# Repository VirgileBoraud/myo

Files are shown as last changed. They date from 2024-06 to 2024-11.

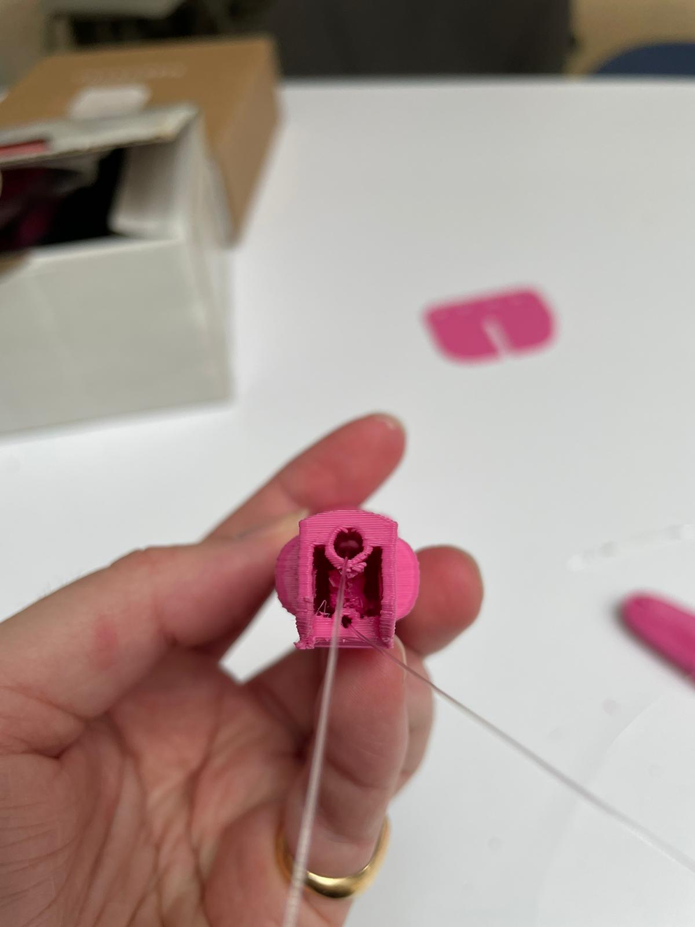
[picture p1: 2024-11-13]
Photos&Vidéos/montage5.jpg

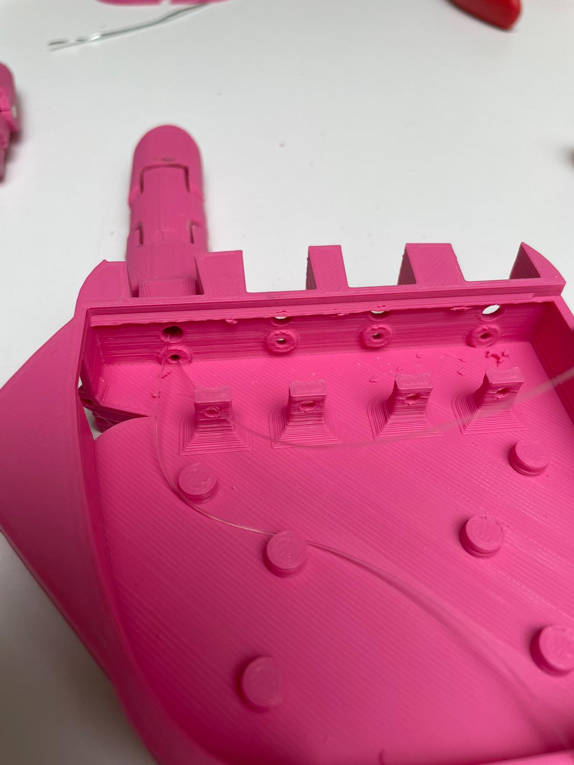
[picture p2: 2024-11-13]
Photos&Vidéos/montage6.jpg

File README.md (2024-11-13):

# Projet_2B09

Vous trouverez tout les programmes dans le dossier correspondant, de même pour les fichiers de modélisation dans le dossier CAO.

Le fichier Projet2B09 est le rapport du projet. 

Lien du projet dont nous nous sommes inspiré:
https://github.com/ashpande/ProstheticHand

Lien présentation canva:
https://www.canva.com/design/DAGHKcEUw74/4D-0PP82Fv-sbKtp_eXOTw/edit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

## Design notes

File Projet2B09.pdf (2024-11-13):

### Page 1 sur 45

# Projet d’avant-bras Myoélectrique

Par Virgile Boraud, Léa Forêt et Rayan Bacha

### Page 2 sur 45

# SOMMAIRE

### Page 3 sur 45

# Remerciements

Nous tenons à remercier toutes les personnes qui ont contribué à la réalisation de ce projet.

Tout d’abord nous remercions chaleureusement et exprimons notre gratitude envers H. Guan, notre référent ainsi que A. Caldas pour leurs conseils et leur encadrement.

Un merci spécial aux membres de l’atelier et du fablab, N. Guillet-Lhermite et C. Thery pour leur assistance technique et leur expertise dans la création de notre prototype.

Merci également à l’ESME ainsi que SupBiotech pour nous avoir offert les ressources nécessaires lors de notre parcours pédagogique.

Enfin, nous remercions nos proches pour leur soutien tout au long du projet.

### Page 4 sur 45

# Présentation

## Qui sommes-nous ?

Nous sommes un groupe de trois étudiants de 4ème année d’école d’ingénieurs composé d’un élève de SupBiotech et deux élèves de l’ESME de la majeure Biomécanique et Robotique médicale. Ce projet s’inscrit dans le cadre de notre formation sous la supervision de Henry Guan, notre référent.

## Quel est notre projet ?

Etant tous trois intéressés par le fonctionnement des prothèses des membres, nous avons décidé de nous orienter vers un projet de ce type. Notre choix s’est porté vers une prothèse de bras, la prothèse de jambe étant soumise à des pressions mécaniques trop difficile à reproduire dans le cadre de ce projet. Nous avons finalement décidé de nous focaliser sur la main et l’avant-bras car les biomécanismes sous-jacents etleurs fonctions ont particulièrement attiré notre attention.

Nous avons décidé d’utiliser un biosignal afin d’actionner l’ouverture et la fermeture de la main. Trois biosignaux s’offrent ainsi à nous : nerveux, cérébraux (encéphalogramme) et myoélectriques. Nous avons déterminé que les signaux myoélectriques conviennent le mieux pour notre projet, ces derniers étant aisément traitables pour capter un seul seuil afin d’activer le moteur responsable de la fermeture/ouverture de la main.

Notre objectif est ainsi d’assembler une prothèse de main myoélectrique et de s’assurer de sa fonctionnalité.

## Organisation de l’équipe

Chacun des membres de l’équipe a été impliqué équitablement dans le projet. Des réunions hebdomadaires avec notre référent ont étaient organisées et plus régulièrement des discussions entre membres de l’équipe. Ces réunions permettant de faire le point sur les avancements de chacune des parties du projet.

Nous avions au début du projet défini quatre grandes parties pour ce projet :

- Recherches préparatoires
- Conception et impressions 3D
- Electronique
- Programmation

### Page 5 sur 45

Nous n’avions pas pris en compte que le montage même de la main avec le besoin de réimprimer et modifier les fichiers SolidWorks nous rajouterai beaucoup de travail et aurait pu être considéré comme une grande partie à part entière.

Figure 1 : Planning initial du projet

En effet, ce planning initial (Figure 1) créé début mars a dû être adapté à de nombreuses reprises. La phase de conception a en effet eu lieu tout au long du projet, suite aux différents problèmes rencontrés lors du montage et des tests, de multiples pièces ayant dû être modifiées.

Concernant la répartition des tâches, nous avons tous participé à la recherche préparatoire pour pouvoir ensuite construire notre projet. Les autres parties ont aussi été traitées de manière globale par l’ensemble de l’équipe avec plus ou moins une spécialisation dans l’un ou l’autre des domaines.

## Contexte médical et problématique

L’amputation de la main et/ou d’une partie de l’avant-bras estsouvent due à des accidents, des blessures ou des maladies (ex : complication du diabète). Cette amputation peut entraîner une perte de mobilité et de fonctionnalité des patients concernés. En effet, la perte de l’articulation du poignet et de la main limite et peut rendre impossible d’accomplir certaines tâches du quotidien essentielles (ex : se nourrir, se déplacer, travailler, …).

C’est pour répondre à cette problématique que nous réalisons ce projet. Notre prothèse a pour but de redonner au patient la possibilité d’attraper des objets permettant ainsi de recouvrer une partie de sa mobilité et de son indépendance.

### Page 6 sur 45

# Anatomie et biomécanique de la main

A] Fonctions de la main

La main opère 2 fonctions principales :

- le tact, permettant la sensibilité tactile, avec reconnaissance du relief, taille et distance de 2 reliefs, consistance et température ainsi que le rétro-contrôle cérébral des gestes fins ou des gestes en force
- la préhension, avec possibilité d’opposition du pouce

Cette action de préhension permet de réaliser diverses fonctions comme illustrées ci-dessous :

Figure 2 : Différentes actions possible par la fonction de préhension de la main

Dans le cadre de notre projet, nous avons donc décidé de fabriquer une prothèse pouvant reproduire cette fonction de préhension.

B] Structure des articulations du doigt

L’articulation métacarpo-phalangienne permet le mouvement des phalanges sur un angle de 120° relatif à l’axe des métacarpes. L’articulation de la première et la seconde phalange permet un mouvement sur un angle de 120° relatif à l’axe de la première phalange. L’articulation de la seconde et troisième phalange permet un mouvement de 80° relatif à l’axe de la seconde phalange.

Figure 3 : Schéma des angles des mouvements des articulations du doigt

Ces mouvements cumulés permettent la flexion du doigt pour la fonction préhensile.

### Page 7 sur 45

Dans le cadre de notre projet, il nous faut donc nous assurer que notre prothèse puisse reproduire ces mouvements de flexion.

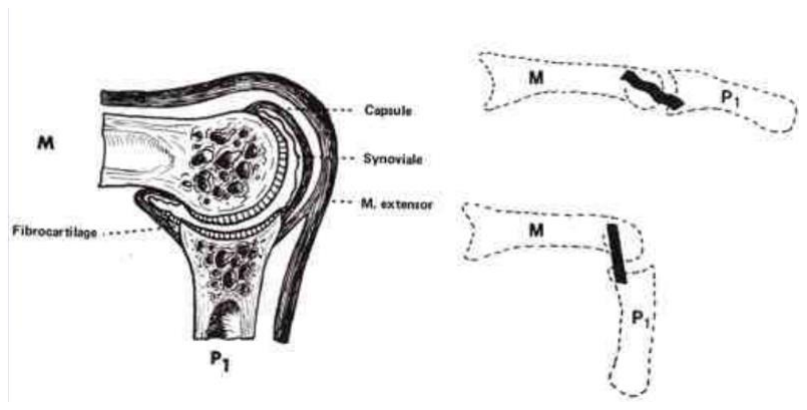
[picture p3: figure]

Figure 4 : Schéma de l’articulation métacarpo-phalangienne

Schéma de l’articulation métacarpo-phalangienne

L’articulation métacarpo-phalangienne permet le mouvement vu précédemment grâce à :

- la forme concave du métacarpe et de la phalange
- la capsule et le liquide synoviale permettant de réduire les frictions du mouvement
- le muscle extenseur de la main, permettant de réaliser le mouvement d’extension du doigt

C] Muscles extenseurs des doigts

### Le muscle extenseur des doigts de la main (en rouge vif sur la figure 5) est positionné sur l’humérus et l’ulna et permet par sa contraction de

déclencher l’extension des doigts.

Figure 5 : Muscle
extenseur des
doigts de la main

### Page 8 sur 45

### Son action est toutefois complémentaire de l’action des muscles extenseurs individuels à chaque doigt (en rouge sur le schéma ci-contre), dont la contraction combinée à celle du muscle précédent

permet l’extension du doigt. Ainsi, pour étendre l’index,

### il faut la contraction du muscle extenseur des doigts de la main et du muscle extenseur de l’index. Pour étendre tous les doigts, il faut la contraction du muscle extenseur des doigts de la main ainsi que de chaque

muscle extenseur du doigt individuel.

D] Flexion des doigts de la main

La flexion des doigts de la main commence par la contraction de deux muscles de l’avant-bras (schéma ci-dessous), le muscle fléchisseur profond des doigts et le muscle fléchisseur superficiel des doigts. Le muscle fléchisseur profond des doigts de la main permet la flexion des articulations interphalangiennes distales des 4 doigts longs, alors que le muscle fléchisseur superficiel des doigts est fléchisseur des phalanges moyennes sur les phalanges proximales et des phalanges proximales sur les métacarpiens.

Figure 7 : Muscles fléchisseur superficiel (gauche) et profond (droite)

Les tendons du muscle fléchisseur profond des doigts courent le long des doigts sur leur face inférieure et la contraction du muscle entraîne ainsi la flexion des doigts.

Figure 6 : Muscle extenseur d’un doigt

### Page 9 sur 45

# Histoire et état de l’art des prothèses

Les prothèses servent à remplacer des organes, des membres ou une articulation par des appareils artificiels permettant de restaurer la fonction compromise. Elle permet non seulement d’essayer de rétablir la fonctionnalité de la partie du corps concernée, mais aussi à améliorer la capacité de mouvement perdu, soutenir des structures corporelles affaiblies ou déformées ou à améliorer l’aspect esthétique (voir les gueules cassées de la
Première Guerre mondiale). Il en existe 2 types, les
externes, comme les membres artificiels, et les internes
comme les valves cardiaques et les implants dentaires. Nous ne parlerons ici que de ceux qui nous intéressent, c’est-à-dire les externes.

Les premières traces de prothèse datent de l’Egypte Antique, des archéologues ont trouvé sur la momie d’une femme une prothèse de doigt de pied faite en bois et en cuir datant de 600 avant JC. Il y serait également fait mention dans les récits de Hérodote en 484-425 av. J.-C. décrivant un substitut en bois d’un pied préalablement, histoire reprise par Plutarque par la suite (voir jambe de Capoue).

Les prothèses ont ensuite été utilisées tout du long du moyen-âge et de la renaissance, généralement en fer ou en métal, certaines pouvaientservir dans des cas pratiques, comme le crochet ou la célèbre jambe de bois des pirates, dont le plus connu utilisateur serait un certain François Le Clerc, surnommé à juste titre “Jambe-de-bois" (voir figure 2). D’autres n’étaient qu’à des fins cosmétiques comme nous pouvons le voir sur la figure 3.

Figure 8 : Plus ancienne prothèse datant de l’Egypte Antique

Figure 9 : Prothèse
en bronze

Figure 10 : Représentation de François Le Clerc

### Page 10 sur 45

C’est au XVIème siècle que les prothèses reçoivent de nouvelles avancées. Un chirurgien français, Ambroise Paré, à créer de nouvelles façons d’amputer ce qui a permis d’avoir de plus grandes chances de guérison et permet l’installation d’appareils de remplacement (voir figure 11) qui permettaient un fonctionnement très basique de la main en métal pour les soldats amputés. Le chirurgien cherchait à reproduire le mouvement naturel grâce à la mécanique.

Différentes avancées durant le 1er et 2ème révolution industrielle permettent certaines avancées dans la fabrication des matériaux composant les prothèses. Celles-ci sont alors plus légères, plus souples, plus robustes et plus fonctionnelles.

Figure 11 : Prothèse médiévale

Figure 12 : Illustration
d’Ambroise Paré

Figure 13 : Prothèse possédant des articulations

Figure 14 : Homme portant des prothèses au début du XIXème siècle

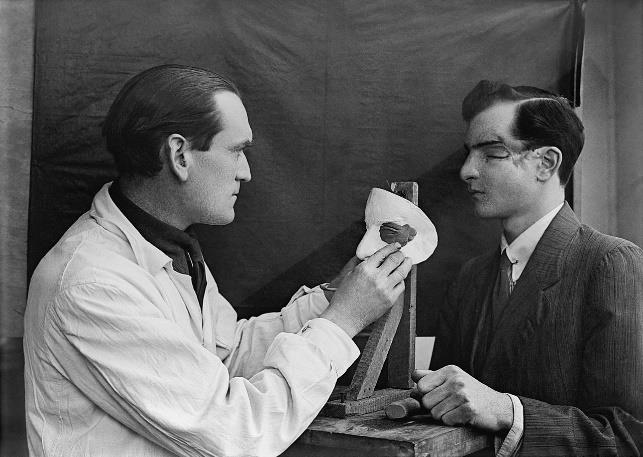
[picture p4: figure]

### Page 11 sur 45

C’est lors de la Première Guerre Mondiale que la demande de prothèsesliées aux blessures de guerre explose. De grandes avancées en chirurgie et prothèse voient le jour. L’un des exemples les plus connus est « les gueules cassées ». Certaines images que nous ne montrerons pas ici montrent des personnes totalement déformées par leurs blessures de guerre se métamorphoser après une chirurgie maxillo-faciale et des prothèses esthétiques ou/et des masques.

C’est après la Seconde Guerre mondiale que l’on voit apparaître une réelle envie par les Etats de financer le développement de prothèses comme les USA en 1948 après diverses controverses sur le manque de considération des soldats amputés. De nombreuses prothèses voient alors le jour. Nous pouvons citer par exemple les prothèses Jaccard (voir figure 16). Faites à partir de matériaux locaux, purement fonctionnels et dépourvus d’artifices esthétiques, elles permettent aux plus démunis de se procurer des prothèses jusqu’alors inaccessibles. Révolutionnant le soin des amputés, ses concepteurs, les frères Jaccard, viendront en aide aux plus démunis à travers le monde.

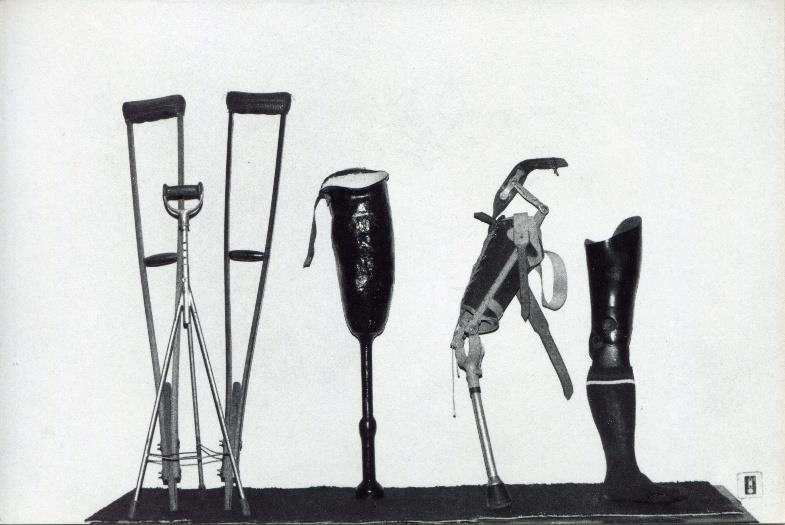
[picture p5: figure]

Finalement, c’est de la fin du XXème siècle à aujourd’hui que les prothèses n’ont cessé de se diversifier. De la simple jambe de bois, aux prothèses bioniques utilisant plusieurs capteurs et des algorithmes complexes, en passant par les prothèses imprimables possibles grâce aux imprimantes 3D. Nul doute que les prochaines décennies verront de nouvelles innovations dans le domaine.

Figure 15 : Confection d’un masque pour un soldat britannique

Figure 16 : Différentes prothèses « Jaccard »

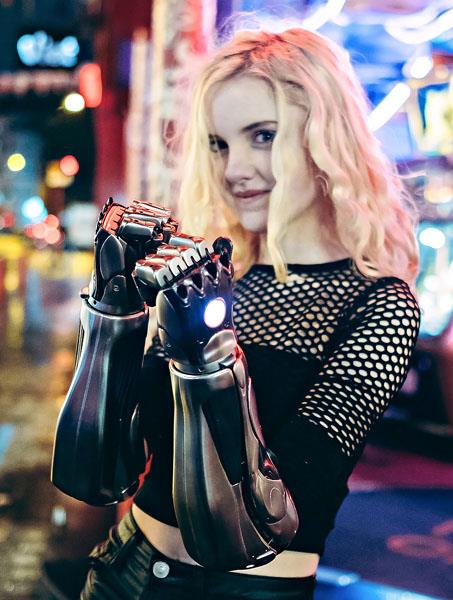
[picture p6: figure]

### Page 12 sur 45

Figure 17 : Prothèse e-NABLE

Figure 18 : Prothèse de bras « Hero-Arm »

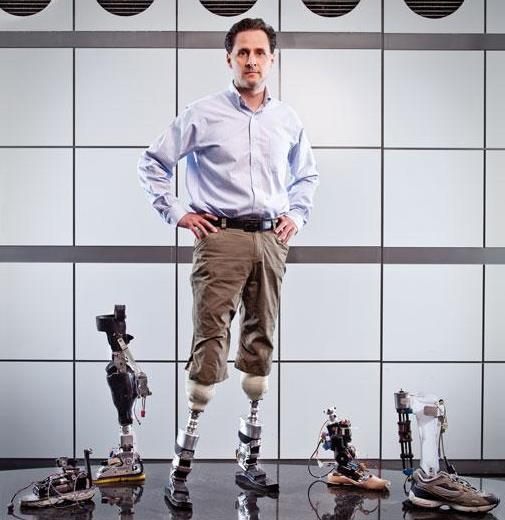
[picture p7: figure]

Figure 19 : Prothèse de jambe HI-tech

### Page 13 sur 45

# Cahier des charges

Nous avons établi un cahier des charges initial pour notre prothèse myoélectrique. Nous nous sommes basés sur notre propre appréciation de ce projet ainsi que différents cahiers des charges proposés dans le cadre de concours de modélisation/innovation disponibles en ligne.

Concernant la structure :

- Imperméable
- Inoxydable
- Aisément nettoyable
- Températures de -10°C à +50°C
- Poids entre 0,5 et 1% du poids de corps total de l’individu à on part sur un homme de 80 kilos à poids entre 400-800g
- Longueur bras (environ 28cm)
- Longueur main (environ 20cm)

Analyse post-projet :

Les critères d’imperméabilité et d’inoxydabilité n’ont pas pu être intégrés au projet final. En effet, le moteur que nous utilisons s’est trouvé trop grand pour être intégré à la prothèse d’une manière permettant le bon déroulement/enroulement du fil. Un axe moteur différent ou de taille réduite aurait permis son intégration dans l’avant-bras sans élément extérieur. Cette partie extérieure du moteur vient aussi mettre à mal ce critère d’imperméabilité. Enfin, les autres éléments (carte Arduino, batterie, ...) sont aussi de taille trop importante pour être intégrés dans la prothèse directement.

Concernant l’alimentation :

- Possibilité de rechargement USB ou batterie interchangeable facilement
- Interrupteur pour allumer et éteindre la prothèse
- Indicateur visuel du niveau de la batterie
- Capable d’alimenter 1 moteur

### Page 14 sur 45

Analyse post-projet :

Nous avons bien une batterie rechargeable qui alimente l’entièreté de notre système, notre batterie comprend un indicateur visuel de son état de recharge et un bouton on/off. Nous avons gardé l’idée de l’interrupteur pour une autre fonctionnalité : le choix du mode de fonctionnement de la prothèse.

Fonctionnalités :

- Ouverture/fermeture de la main par utilisation d’un capteur sur les muscles rémanents du bras (biceps et/ou triceps/brachioradialis) (1 moteur)

-Recréation de sensation de touché par des moteurs vibrants sur l’avant-bras/bras

-Fixation non invasive, avec liner en silicone + sockets placés sur le membre résiduel

-Option : possibilité d’augmenter progressivement le poids de la prothèse

-Option : espace de stockage

-Option : Adapté le bras aux sport ou loisir du patient

-Option : articulation du poignet

Analyse post-projet :

Pour commencer, aucune des options envisagées n’a pu être mise en place sur notre projet. En effet, de nombreux problèmes liés au fonctionnement de la prothèse et au modèle 3D ont trop retardé le projet pour que nous ayons du temps à consacrer à ces fonctionnalités secondaires. Enfin, il en va de même avec les fonctionnalités de touché et de fixation.

# Schéma Synoptique

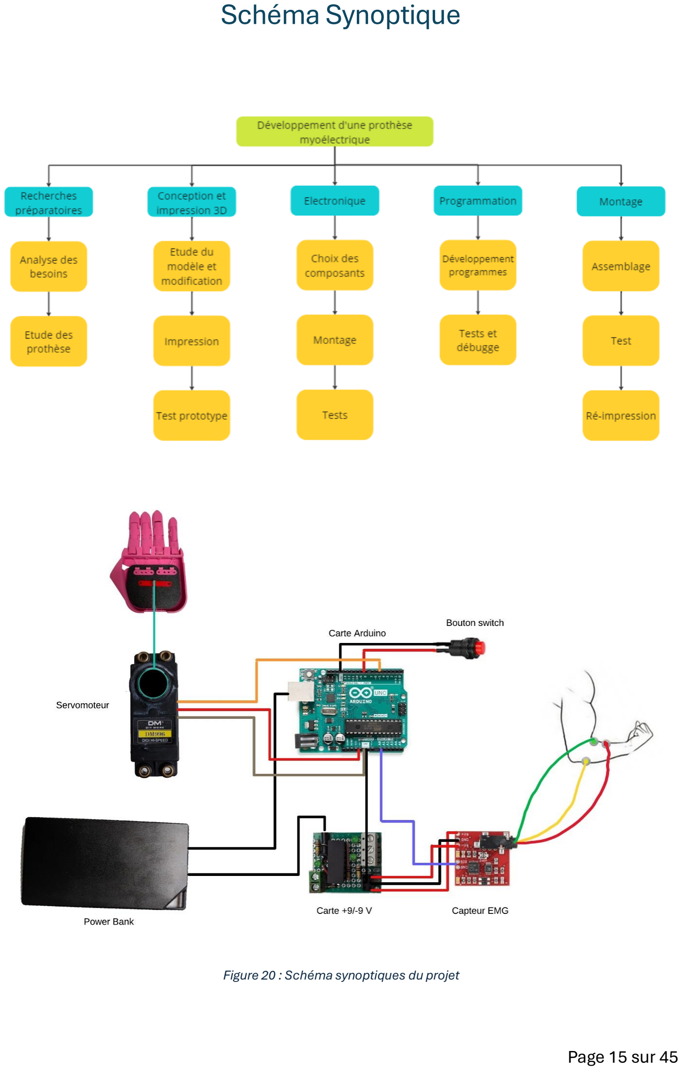
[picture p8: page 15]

### Page 15 sur 45

Figure 20 : Schéma synoptiques du projet

### Page 16 sur 45

Nous nous sommes laissés environ trois semaines pour les recherches préparatoires, nous avons ensuite commencé les impressions 3D en avril tout en réfléchissant aux composants électroniques à utiliser et à faire ces sessions de test de ces composants afin de valider leur usage pour notre projet. Une fois tous ces composants validés, nous avons fait la demande officielle le 2 mai pour pouvoir commencer le montage final. Au fur et à mesure de l’impression 3D nous avons voulu commencer le montage mécanique de la main, mais le besoin de réimpression régulier suite aux erreurs d’impression et au besoin de modifier le modèle, une grande partie du montage a été réalisée sur la fin du projet en mai.

### Page 17 sur 45

# Détail matériel

## 1) La partie Electronique

## Les composants

### Une carte Arduino uno :

L’Arduino Uno est une des cartes de développement des plus utilisée. Elle est basée sur un microcontrôleur ATmega328P qui fonctionne à une fréquence de 16 MHz. Elle comprend une mémoire flash de 32 Ko (pour le programme), 2 o de RAM et 1 Ko de mémoire EEPROM (pour le stockage des données non volatiles). Les entrées sorties comprennent 14 broches numérique dont 6 PWM (Modulation de Largeur d’Impulsion) pour contrôler des périphériques comme des servomoteurs et 6 broches analogiques pouvant lire les données venant de

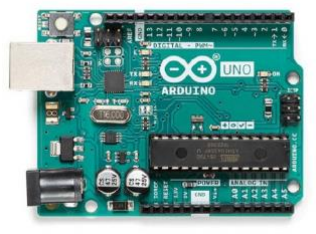
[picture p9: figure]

capteurs. L’alimentation peut se faire via une connexion USB en 5V et peut servir pour connecter des périphériques électriques. L’avantage de cette carte de développement c’est qu’elle est simple d’utilisation, open-source avec beaucoup de ressources et de bibliothèques accessibles.

### Un servomoteur (DM996) :

Les servomoteurs sont des dispositifs électromagnétiques utilisés pour contrôler la position d’un mécanisme, ils convertissent un signal électrique en un mouvement mécanique.

Ce moteur de DIY More est un servomoteur fabriqué en métal, ses engrenages sont solides et assurent une longue durabilité même lors d’une utilisation intensive.

Ce moteur offre une vitesse de fonctionnement de 0,17s / 60 degrés à 4.8V et de 0,13s / 60 degrés pour une tension de à 6.0V sans charge. Le couple de décrochage est de 9 kg/cm à 4.8V et de 15kg/cm pour une tension de 6.0V. Ces deux performances assurent des mouvements puissants et assez précis.

### Page 18 sur 45

### Un capteur EMG (Muscle Sensor V3) :

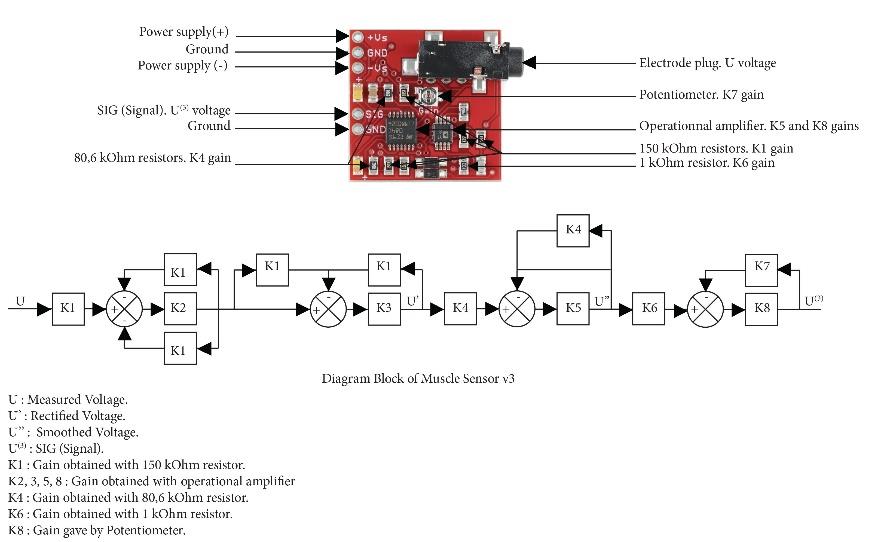
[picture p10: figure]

C’est un capteur conçu pour mesurer l’activité électrique des muscles, pour cela, on place des électrodes sur la peau pour capter les signaux électriques émis lors de la contraction musculaire. Les signaux musculaires sont de l’ordre des µV à quelques mV, le capteur utilise donc un circuit d’amplification important (gain de 1000) permettant de mieux détecter les potentiels. Le capteur renvoie ensuite en sortie un signal analogique variant entre 0 (muscle non contracté) et 1023 (muscle très fortement contracté). Pour l’utiliser, ce capteur doit être alimenté par une alimentation bipolaire de +/- 9V.

### Les Alimentations :

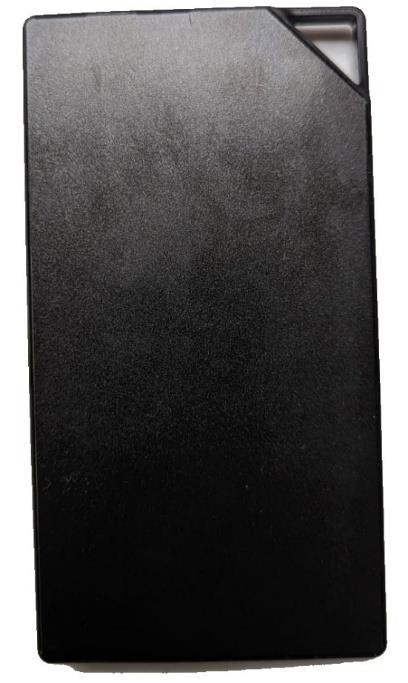
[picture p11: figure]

Pour alimenter ces composants, nous avons utilisé une Power Bank permettant d’envoyer du 5V stable à notre carte Arduino. La Power Bank permet aussi à notre projet d’être autonome et ne pas avoir besoin d’être constamment branché à un ordinateur, ce qui le rendrait inutilisable en condition réelle. De plus elle pourra être rechargée de nuit, lorsque notre prothèse n’est pas utilisée. Cette même Power Bank alimente aussi une carte +/-9 V faite par Nicolas Guillet-Lhermite qui, elle, permettra d’alimenter le capteur EMG. Enfin, le moteur lui sera alimenté en 5V à partir de la carte Arduino.

### Page 19 sur 45

## Schéma électronique

Figure 21 : Schéma électroniquee

Description :

Nous alimentons notre système grâce à la PowerBank qui transmet du 5V stable à la carte Arduino et à la carte +9V/-9V via câble USB. Pour alimenter le capteur EMG, nous relions les bornes +9, -9 et la masse de la carte +9/-9V aux bornes +Vs , -Vs et GND respectivement. Nous envoyons ensuite le signal du capteur EMG via la borne SIG vers la carte Arduino, sur la broche d’entrée analogique A0. Nous branchons ensuite le moteur à la carte Arduino sur les broches 5V, GND et une broche PWM (ici la broche 5). Enfin, nous avons relié les masses des différents composants entre-elles pour assurer le bon fonctionnement de tous.

Ce système est portable et nous permet une autonomie de plusieurs heures sans restriction de branchement à un ordinateur ou une batterie fixe.

### Page 20 sur 45

Figure 22 : Montage électronique

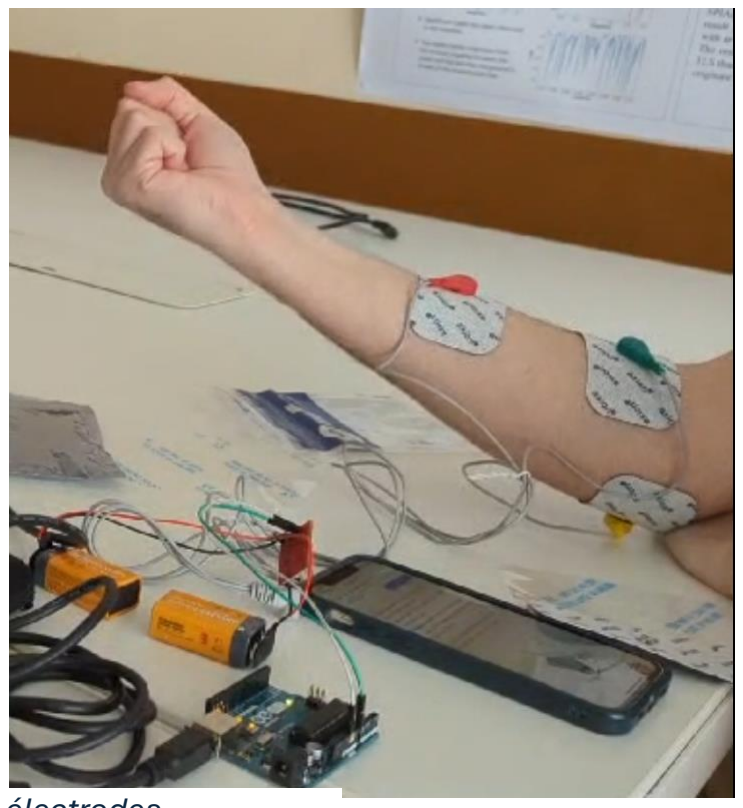
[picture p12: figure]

### Page 21 sur 45

## Tests des composants

### Test 1 : Capteur EMG

Après avoir réalisé le montage et avoir bien vérifié que le microprocesseur fonctionne avec le capteur EMG, nous avons pu effectuer plusieurs tests afin de mieux comprendre le fonctionnement de celui-ci. La première carte qui nous avait été fournie ne fonctionnant pas, car étant une « copie » d’Arduino, elle n’était alors pas compatible. Nous utiliserons une carte Arduino officielle. Ce premier montage nous a permis de constater plusieurs éléments qui se révéleront utiles par la suite.

Nous avons tout d’abord installé, en utilisant les emplacements comme montrés par la

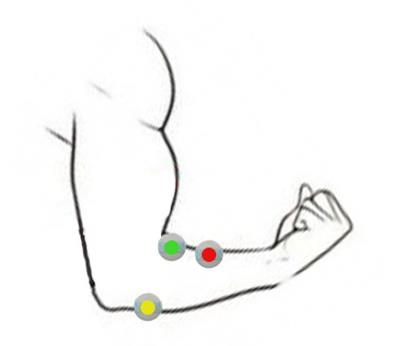
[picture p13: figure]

figure 23, les patchs en gel sur l’avant-bras de notre cobaye.

Notre cobaye a alors contracté ce muscle en fermant son poing. Nous pouvons alors voir le résultat de la contraction du muscle sur les figures 25 et 26. Nous constatons l’apparition d’un « plateau » qui pourra alors servir par la suite de seuil de détection pour activer la fermeture ou l’ouverture de la main.

Cependant, contrairement à ce que pourrait faire entendre la figure 27, plusieurs de ces seuils, dans un intervalle très court, sont visibles. Déterminer un temps minimum avant que le programme ne détecte à nouveau ceux-ci afin d’éviter des « spasmes » d’ouverture-fermeture à chaque contraction pourrait être une solution viable.

Enfin, il reste du bruit qui pourrait causer des soucis lors de la détection. Nous verrons s’il est utile de le filtrer ou s’il ne cause aucun souci lors des prochains tests.

Figure 23 : Placement des électrodes

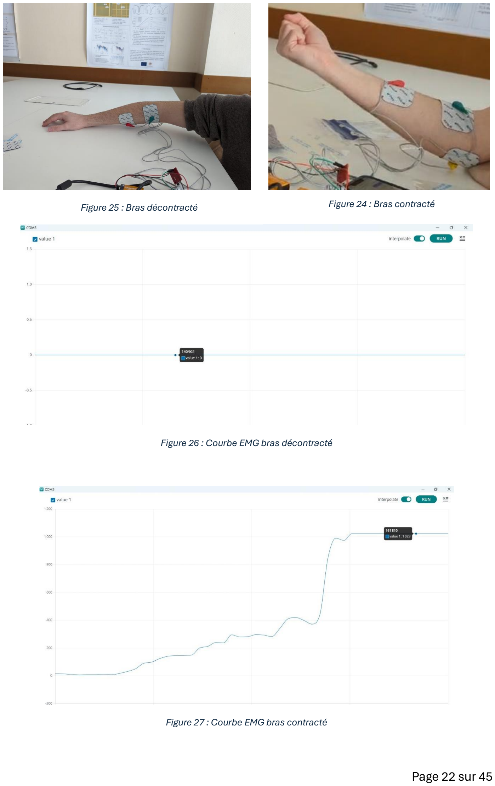
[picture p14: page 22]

### Page 22 sur 45

Figure 26 : Courbe EMG bras décontracté

Figure 27 : Courbe EMG bras contracté

Figure 25 : Bras décontracté | Figure 24 : Bras contracté

### Page 23 sur 45

### Test 2 : Le servomoteur

Le but de ce test était de vérifier les branchements au niveau du moteur et de vérifier son bon fonctionnement.

Figure 28 : Montage servomoteur

Pour cela, nous branchons le moteur aux pins 5V, GND et PWM 5 comme sur le schéma électronique global et nous avons réussi grâce au programme que vous trouverez en annexe à faire tourner le moteur sans aucun souci validant ainsi nos branchements.

### Page 24 sur 45

### Test 3 : Electronique globale :

Le but était de voir si tous nos composants fonctionnaient ensemble et réagissaient de la bonne façon. Ce test nous a permis de choisir les valeurs de seuils en fonction des personnes portant notre système. Nous avons aussi pu choisir une valeur d’attente entre chaque détection de seuil qui nous paraissait adaptée.

Nous avons commencé par réaliser le montage électrique présenté précédemment (figure 22). Ensuite, comme pour le test du capteur EMG, nous avons placé les électrodes sur notre cobaye comme indiqué sur les figures 24 et 25.

Pour nous assurer que notre moteur ne fonctionnera pas lors de mouvement naturel du bras, nous avons effectué différents mouvements comme la marche, la course et d’autres mouvements divers en étudiant les valeurs retournées par le capteur électromyogramme . Nous avons constaté que globalement les mouvements sans intention de fermeture de la main sont situés en dessous de 600. Nous avons donc pu définir les seuils d’intention de fermeture de la main suivants pour les différentes personnes ayant testé notre système.

Testeur | Output EMG mouvement divers | Output EMG intention de fermeture
Virgile | 0 à 600 | 700
Rayan | 0 à 530 | 550
Léa | 0 à 430 | 450

Nous avons déterminé au cours de ce test qu’une seconde d’attente entre la recherche d’une nouvelle intention de fermeture et/ou d’ouverture est suffisante.

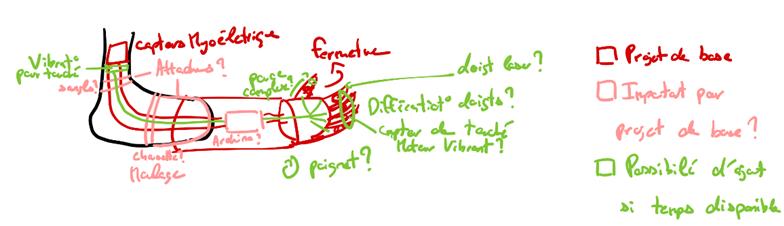
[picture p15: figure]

### Page 25 sur 45

## 2) La partie Mécanique :

## Choix du modele 3D

Figure 29 : Idée initiale de prothèse

Nous avons pris le temps de choisir le modèle que nous souhaitions utiliser pour la main. Nous connaissions les modèles à câble, omniprésents sur le marché. Différents types de modèles « prêts à être imprimés » étant disponibles, nous savions que nous pouvions compter sur un de ceux-ci si nous le désirions. Cependant, le but de ce projet étant d’apprendre, nous avons fait le choix de ne pas copier un modèle existant sans l’avoir étudié préalablement. Nous avons alors réfléchi nous-mêmes aux différents types de mécanismes d’ouverture-fermeture que nous pouvions utiliser et avons posé notre choix sur un système d’ouverture fermeture par engrenage (voir figure 30)

Figure 30 : Schéma de réflexion sur le modèle à engrenage

### Page 26 sur 45

Cependant, dans le cadre de ce projet, l’idée de modéliser nous-mêmes la main semblait trop longue et complexe. Nous nous sommes alors mis à chercher des modèles sur Internet ne possédant pas de guides, afin d’apprendre par nous-mêmes comment l’assembler (nous rencontrerons de nombreux problèmes par la suite, qui nous a permis d’en apprendre beaucoup). Nous avons trouvé très peu de modèles concluants, certains étant payants, d’autres ne possédant pas de fichiers traitables avec SolidWorks ou possédant des parties trop complexes pour être imprimés par les imprimantes 3D de l’ESME. L’idée d’un mécanisme à engrenages s’estompant de jour en jour, nous nous sommes résolus à regarder les modèles à câbles/fils, plus faciles à mettre en place et à imprimer.

Deux modèles se sont alors écartés du reste. Le premier, l’e-NABLE, simple, robuste, modifiable facilement. Mais même trop simple, nous ne voulions nous résoudre à ce modèle seulement si le second ne pouvait fonctionner. Nous en venons alors au deuxième. Il s’agit d’un modèle fait lors d’un concours par des étudiants du MIT ayant remporté un prix. Les fichiers fournis étaientsous format SolidWorks, la documentation complète et le mécanisme paraissait fonctionner théoriquement.

Cependant, nous ne le savions pas encore, mais il n’avait justement été mis en pratique que partiellement. La documentation portait des images du modèle imprimé, mais aucune application concrète ou assemblage fini. Un problème qui est revenu tout du long lors des différents tests que nous avons réalisés et qui nous a fait perdre beaucoup de temps (voir montage du système).

Nous avons certes rencontré de nombreux problèmes avec ce modèle en nous obstinant à le garder, mais cela nous a permis de mettre en évidence des problématiques réelleslors de la conception des prothèses. Nul doute que d’autres se poseraientsi nous avions plus de temps, comme l’adaptation aux différentes amputations et autres.

### Page 27 sur 45

## Montage du modèle

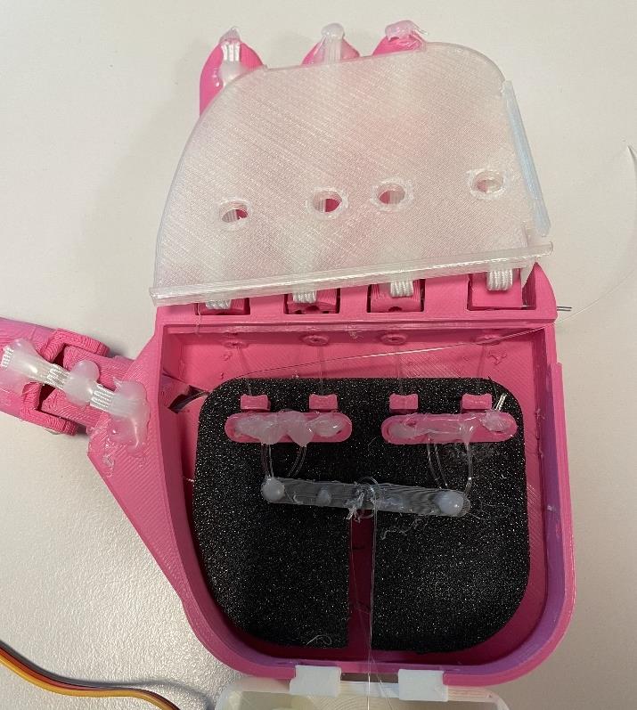
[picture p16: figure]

Le montage de la main a dû se heurter à deux problèmes majeurs, tout d’abord les problèmes d’impression, le second provenant de la mauvaise conception du modèle original.

Le premier vient des imprimantes du fablab. Nous avons malheureusement rencontré des soucis lors de leurs utilisations. Parfois la buse était cassée et nous avons dû la faire remplacer, d’autres fois l’impression avait décalé une couche, détruisant alors le modèle en train d’être imprimé et retardant alors l’impression. Le manque de précision entraînait aussi des soucis pour les petites pièces qui ont dû souvent être relancées en impression. Afin d’accélérer l’impression du modèle, nous avons décidé de réaliser les impressions avec les imprimantes de l’ESME et de SupBiotech. Toutefois, les imprimantes disponibles à SupBiotech ne sont pas de meilleure qualité et souffraient de différents problèmes de réglage.

Le deuxième vient du modèle. Comme nous avions peu de temps pour concevoir un modèle, nous avons donc décidé de récupérer celui fait par des élèves du MIT ayant reçu un prix. La datasheet et la mécanique étant détaillées, nous avions confiance en celui-ci, mais elle s’est avérée être peu fonctionnelle dans son format original. Nous avons alors dû modifier certaines parties et s’adapter avec les moyens que nous avions pour fournir une démonstration correcte. Nous avons par ailleurs prévu d’utiliser le e-NABLE en plan de secours.

A posteriori, beaucoup de choses seraient à refaire sur ce modèle, mais nous saurions comment nous y prendre et ces soucis nous ont permis d’en apprendre bien plus que si nous nous étions contentés de prendre le modèle sur Internet. Si nous devions lister les soucis majeurs du modèle orignal, nous dirions :

Figure 31 : Intérieur de la main

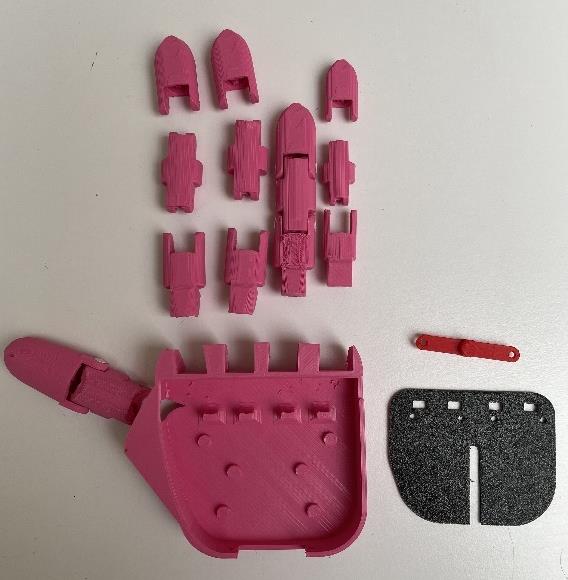
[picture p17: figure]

### Page 28 sur 45

- Manque de retour des doigts (réglable avec élastique)
- Problème sur le pouce (refaire la partie du pouce entièrement)
- Pas assez de marge entre la mécanique intérieure et la plaque la couvrant (rajouter 1-2 mm de distance devrait suffire)
- Simplification des passages de câbles à l’intérieur de la main
- Nous pourrions aussi envisager 1 servomoteur par doigt, ce qui simplifierait le mécanisme et réduirait aussi les frottements (la barre principale et les barres secondaires n’existant alors plus).

### Les différentes étapes d’assemblages

Nous avons tout d’abord imprimé toutes les pièces de la main. Il y a malheureusement eu beaucoup de ratés dus aux problèmes d’impression. Nous pouvons cependant voir les pièces réunies sur la figure 32. Il y manque cependant les 2 barres secondaires que nous pourrons observer sur les prochaines photos.

Nous avons ensuite inséré la plaque centrale dans la paume de la main, sans oublier d’y insérer précédemment la barre principale (rouge). Nous avons enfin connecté les câbles aux trous situés en bas des doigts
(voir figure 34). Le câble ne passera
par la suite que dans le passage du
bas car cela causait des soucis lors de la fermeture de la main (le fait de tirer sur les câbles ne ferme pas le doigt si le câble passe par les deux passages).

Figure 32 : Les pièces de la main

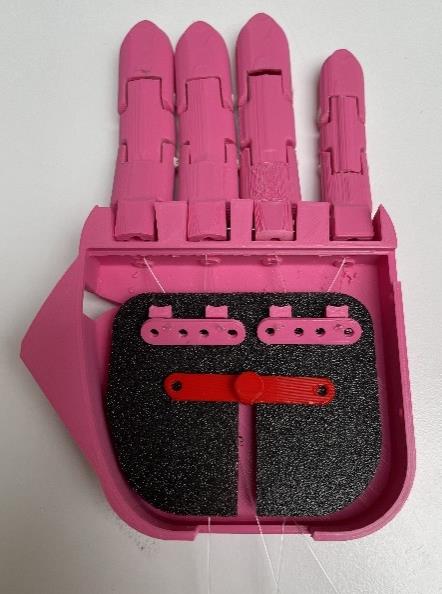
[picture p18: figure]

Figure 33 :Assemblage de la plaque (noir), des barres et des câbles

Figure 34 : Passage des
câbles dans les doigts

### Page 29 sur 45

Nous avons ensuite, connecté les deux barres secondaires, à la barre principale et enroulé un fil autour de la barre principale. C’est ce fil qui sera tiré par le moteur et permettra de fermer la main. Les points de colle visibles sur la figure 35 et les prochaines sont présents car le mécanisme n’est pas assez robuste. En effet, les fils « glissaient » constamment en dehors de leur trou alors qu’ils y étaient bien attachés. Nul doute que notre manque de compétences en nœuds a dû jouer. Nous pouvons aussi voir que nous avons rajouté le pouce sur la figure 36.

Finalement, nous avons rajouté la plaque du dessus (en blanc-transparent). La main ne possédant pas de système de retour (pour que les doigts soient naturellement droits et se réouvre une fois fermés par le moteur), nous avons opté pour les rajouter nous-mêmes à l’aide de point de colle. Il s’agit alors d’élastiques de la marque DIY qui nous ont gentiment été fournis par Capucine. Cependant, ceux-ci sont trop « puissants » et empêchent la main de se refermer totalement. Des emplacements dédiés à des élastiques moins puissants comme des élastiques d’appareils dentaires seraient une solution intéressante pour remédier à ce problème. Ne pouvant pas remodéliser, réimprimer et remonter la main en entier, cette solution sera gardée. Nous pouvons aussi constater le rajout d’un avant-bras et de l’emplacement du moteur (voir figure 36).

Figure 35 : Assemblage des fils de liaison

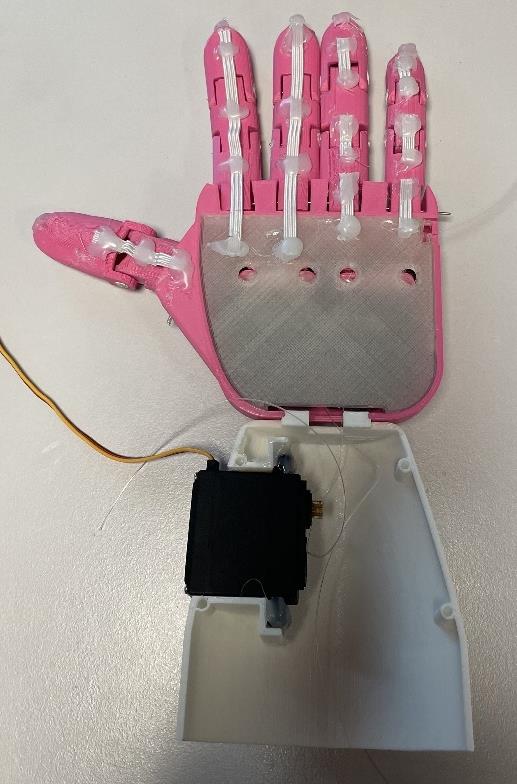
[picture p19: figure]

Figure 36 : Assemblage final

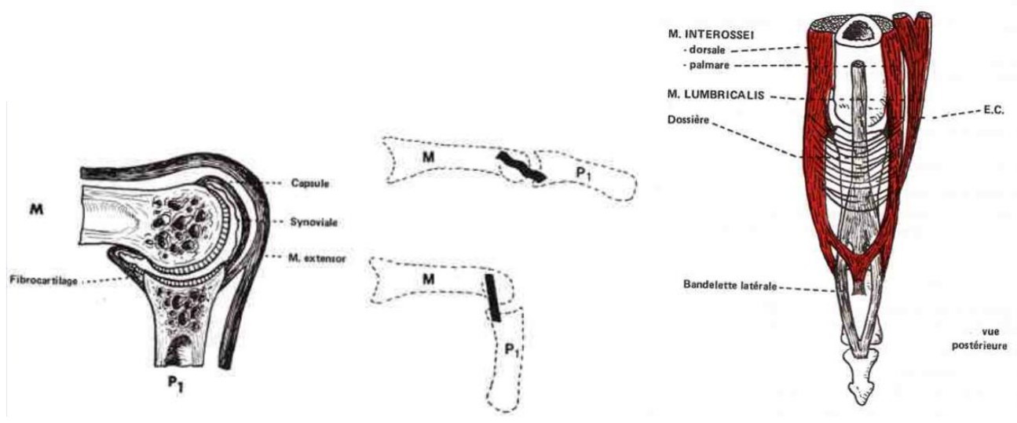
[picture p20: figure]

### Page 30 sur 45

### Fonctions anatomiques

Figure 37 : Schéma de l’articulation des phalanges et des muscles extenseurs du doigt

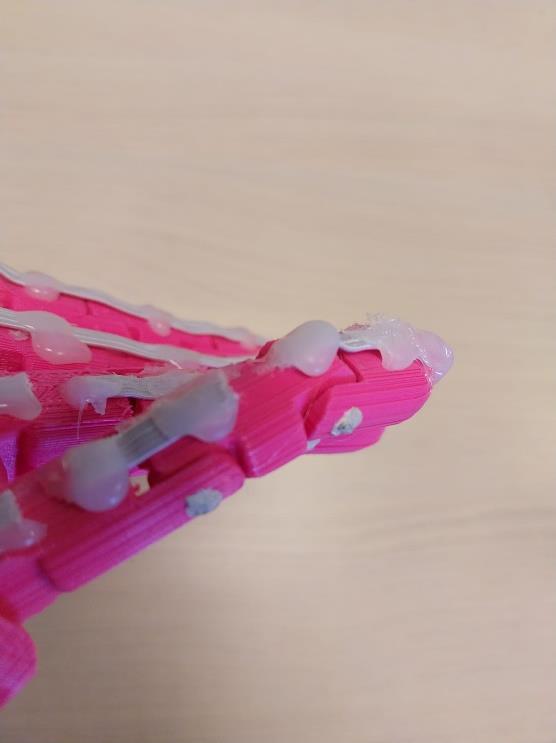
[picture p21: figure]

Figure 38 : Doigt de la prothèse

Comme illustrée ci-dessus, notre prothèse reproduit les articulations des phalanges. Un axe est inséré afin de permettre le mouvement de l’articulation, ce qui est la principale différence avec l’articulation biologique. L’absence de liquide de lubrification (liquide synovial) augmente les frictions au niveau de l’articulation et notre prothèse nécessite donc plus de force que l’articulation biologique pour la flexion des doigts.

Les élastiques placés le long des doigts et permettant l’extension des doigts prennent ainsi le rôle des muscles extenseurs des doigts, en étant placés à des positions similaires à ce muscle.

### Page 31 sur 45

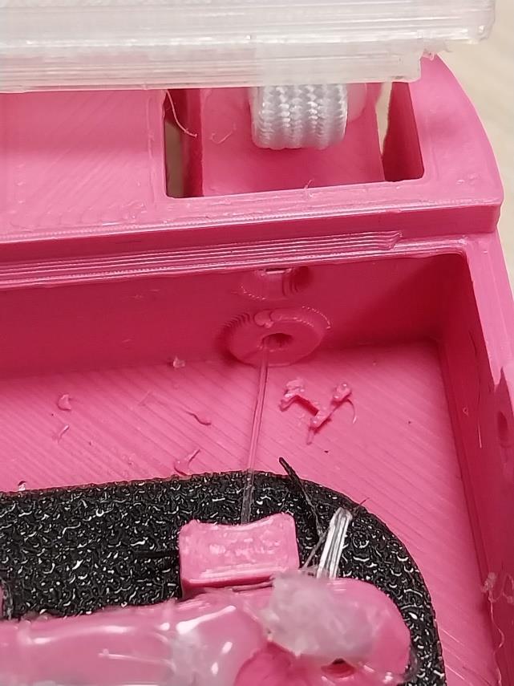
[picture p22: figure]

Figure 39 : Entrée du fils dans le doigt par la paume

Figure 40 : Muscle fléchisseur profond des doigts

### La flexion des doigts est assurée dans notre prothèse par un fil courant le long du doigt sur sa face inférieure, d’une manière similaire à celle des tendons du muscle

fléchisseur profond des doigts. La tension sur ces fils est générée par le moteur situé dans l’avant-bras, reproduisant ainsi la contraction du muscle fléchisseur profond des doigts.

### Page 32 sur 45

# Programmes et Organigrammes

Nous avons réalisé deux programmes différents permettant de contrôler notre prothèse en fonction du choix du patient et de ses capacités, il pourra choisir entre une fermeture lorsque nous captons un signal EMG supérieur à un seuil puis l’ouverture pour une nouvelle détection de seuil sans qu’il n’ait à fournir un effort constant sur toute la période. Ce programme peut être utilisé dans le cas des patients qui ont soit une force musculaire limitée (qui ne peuvent pas fournir un effort constant), qui ont soit une force musculaire qui varie dans la journée oui qui sont atteints d’une maladie neuromusculaire et qui ne peuvent plus fournir un effort sur une plus longue période.

Le second programme au contraire demande une contraction constante pour la fermeture de la main, qui ne ressemble donc plus à une fonctionnalité normale de la main. Cette version fonctionne pour les patients ayant une bonne force résiduelle avec un bon contrôle musculaire, elle sera plus adaptée pour des patientsjeunes et en bonne santé qui peuvent fournir un effort prolongé.

Pour choisir le programme à utiliser, nous avons ajouté à notre système un bouton switch qui lorsqu’il est pressé réalise le premier programme que nous avons décrit et lorsque celui-ci est relâché, le deuxième programme est lancé. Ce qui permet à un utilisateur de notre prothèse de changer le programme selon sa force, sa concentration et son envie en temps réel.

Figure 41 : Organigramme programme global

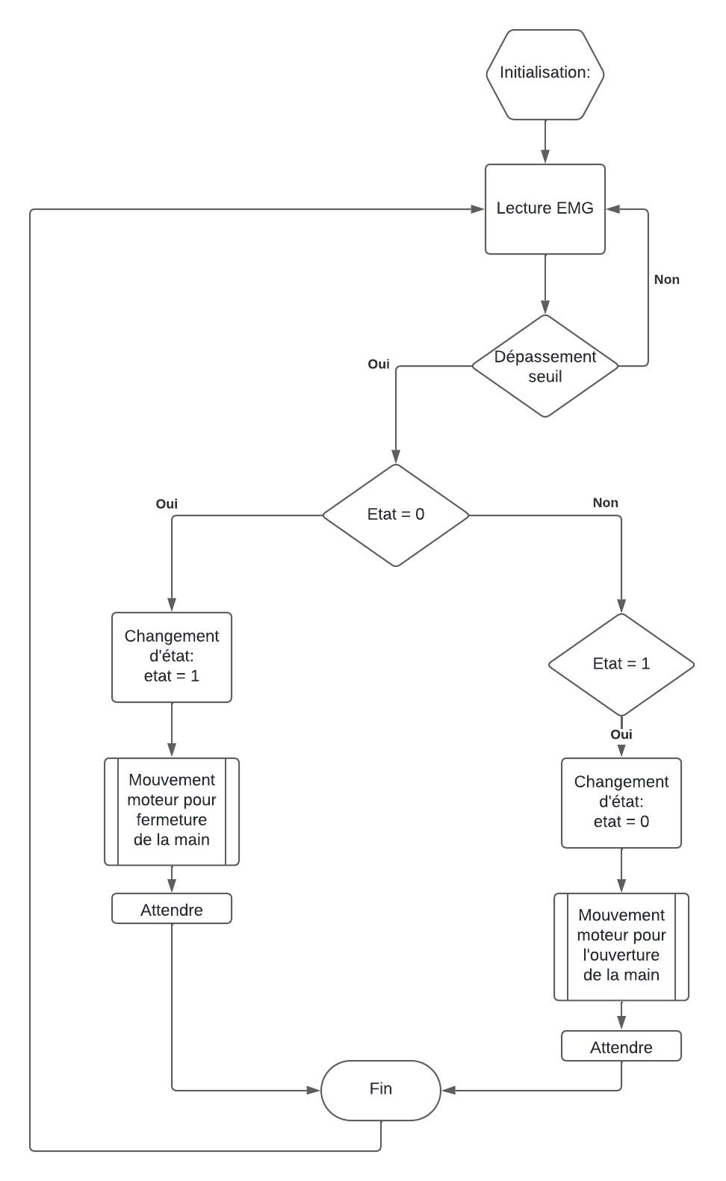
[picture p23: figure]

### Page 33 sur 45

Première version :

- Organigramme

Figure 42 : Organigramme version 1

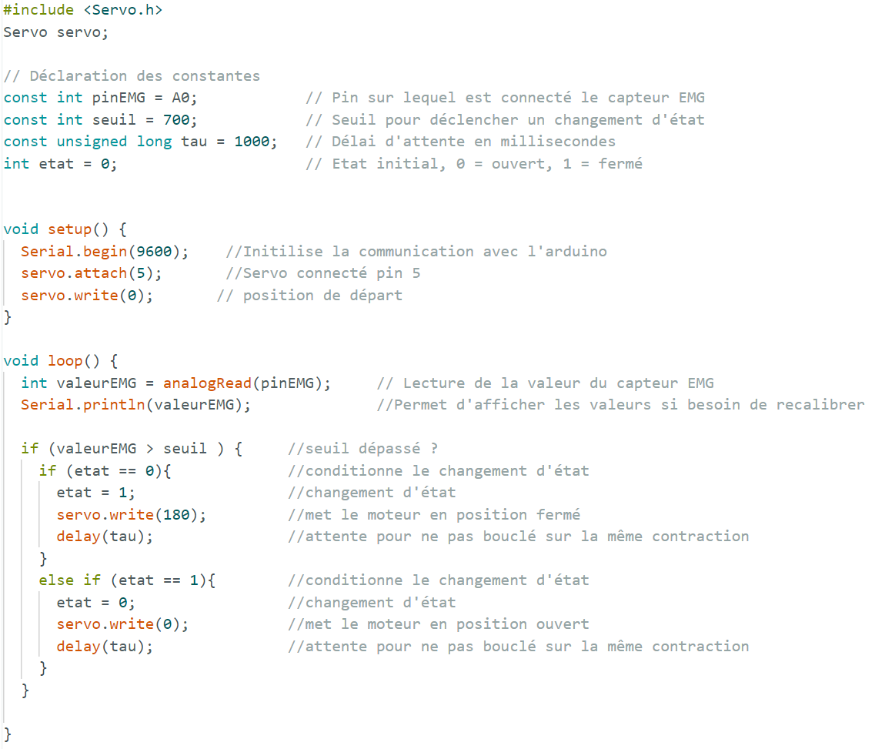
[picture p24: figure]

### Page 34 sur 45

- Code avec commentaires

Comme expliqué précédemment, ce code permet d’effectuer l’ouverture et la fermeture de la main lorsque le seuil est dépassé sans avoir besoin de fournir un effort constant.

### Page 35 sur 45

Deuxième version :

- Organigramme

Figure 43 : Organigramme version 2

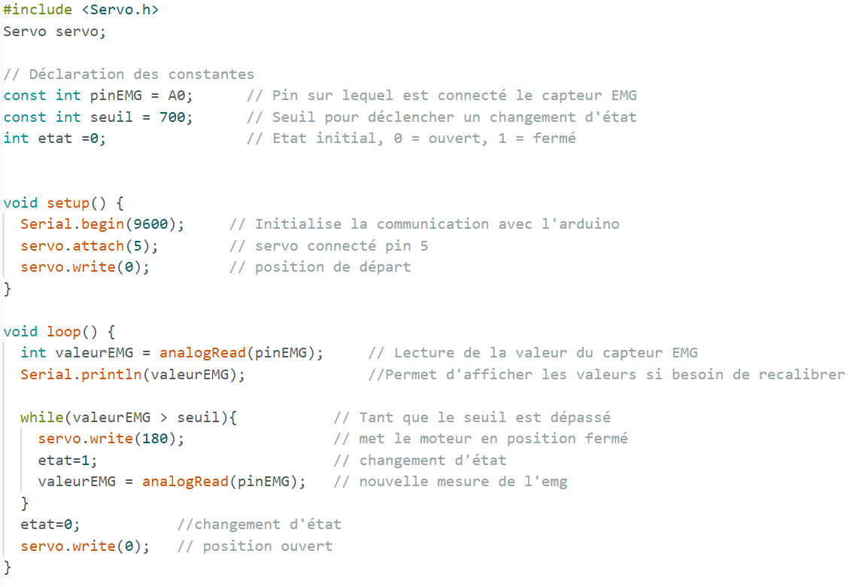
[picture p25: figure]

### Page 36 sur 45

- Code avec commentaire

Au contraire, ce programme permet d’effectuer la fermeture de la main lorsque nous avons un signal EMG constant.

### Page 37 sur 45

# Conclusion

Ce projet nous a permis de voir le fonctionnement et la réalisation d’une prothèse à partir de technologies accessibles qui répond partiellement à notre cahier des charges de départ.

Nous avons eu l’opportunité de travailler sur différents sujets comme l’acquisition de signaux myoélectriques pour distinguer les intentions de mouvement, la conception et modélisation 3D pour modifier et créer des pièces de notre projet. Ainsi qu’une partie électronique simple mais efficace dans le cadre de notre projet qui permet de répondre à un point important du cahier des charges, l’autonomie du système.

Cependant, il existe de nombreux axes d’amélioration qui pourrait être mise en place. En effet, nous pourrions reprendre entièrement le modèle 3D de la main pour que celui-ci soit plus fonctionnel. Travailler sur l’agencement des composants à l’intérieur de notre prothèse et donc voir s’il serait possible d’avoir du matériel plus petit pour un prix égal. Enfin, au commencement du projet, nous avions de nombreuses idées d’options à rajouter qui serait à notre avis très utile pour l’utilisation d’une prothèse au quotidien. Par exemple, l’ajout d’un feedback au patient lorsque l’utilisateur touche un objet et de plus grande liberté de mouvement (1 servomoteur pour chacun des doigts).

En conclusion, notre projet a franchi des étapes importantes vers la réalisation d’une prothèse myoélectrique fonctionnelle. Les problèmes rencontrés nous ont offert des opportunités de réflexion et de recherche qui nous aideront dans notre future vie professionnelle.

### Page 38 sur 45

# Bibliographie

### Modèle à engrenage de mains :

### https://cults3d.com/fr/mod%C3%A8le-3d/divers/hand-robot-mano-robotica

### Guide pour mains engrenage complet :

### https://wikifab.org/wiki/Proth%C3%A8se_de_main_command%C3%A9e_par_des_cap-

teurs_musculaires#%C3%89tape_1_-_Impression_des_pi%C3%A8ces (https://wikifab.org/wiki/Proth%C3%A8se_de_main_command%C3%A9e_par_des_capteurs_musculaires)

### Lien fusion de l’e-NABLE :

### https://myhub.auto-

desk360.com/ue2d15baa/g/shares/SH56a43QTfd62c1cd968fc71eea4b8ef3f38* (https://myhub.autodesk360.com/ue2d15baa/g/shares/SH56a43QTfd62c1cd968fc71eea4b8ef3f38*)

### Lien vers le GitHub du modèle 3D utilisé :

### https://github.com/ashpande/ProstheticHand

### Lien vers le GitHub de notre projet :

### https://github.com/Eclyps/Projet_2B09

### Page 39 sur 45

# Liste des figures

FIGURE 1 : PLANNING INITIAL DU PROJET | 5
FIGURE 2 :DIFFERENTES ACTIONS POSSIBLE PAR LA FONCTION DE PREHENSION DE LA MAIN | 6
FIGURE 3 : SCHEMA DES ANGLES DES MOUVEMENTS DES ARTICULATIONS DU DOIGT | 6
FIGURE 4 : SCHEMA DE L’ARTICULATION METACARPO-PHALANGIENNE | 7
FIGURE 5 : MUSCLE EXTENSEUR DES DOIGTS DE LA MAIN | 7
FIGURE 6 : MUSCLE EXTENSEUR D’UN DOIGT | 8
FIGURE 7 : MUSCLES FLECHISSEUR SUPERFICIEL (GAUCHE) ET PROFOND (DROITE) | 8
FIGURE 8 : PLUS ANCIENNE PROTHESE DATANT DE L’EGYPTE ANTIQUE | 9
FIGURE 9 : PROTHESE EN BRONZE | 9
FIGURE 10 : REPRESENTATION DE FRANÇOIS LE CLERC | 9
FIGURE 11 : PROTHESE MEDIEVALE | 10
FIGURE 12 : ILLUSTRATION D’AMBROISE PARE | 10
FIGURE 13 : PROTHESE POSSEDANT DES ARTICULATIONS | 10
FIGURE 14 : HOMME PORTANT DES PROTHESES AU DEBUT DU XIXEME SIECLE | 10
FIGURE 15 :CONFECTION D’UN MASQUE POUR UN SOLDAT BRITANNIQUE | 11
FIGURE 16 :DIFFERENTES PROTHESES « JACCARD » | 11
FIGURE 17 : PROTHESE E-NABLE | 12
FIGURE 18 : PROTHESE DE BRAS « HERO-ARM » | 12
FIGURE 19 : PROTHESE DE JAMBE HI-TECH | 12
FIGURE 20 : SCHEMA SYNOPTIQUES DU PROJET | 15
FIGURE 21 : SCHEMA ELECTRONIQUEE | 19
FIGURE 22 : MONTAGE ELECTRONIQUE | 20
FIGURE 23 : PLACEMENT DES ELECTRODES | 21
FIGURE 24 : BRAS CONTRACTE | 22
FIGURE 25 : BRAS DECONTRACTE | 22
FIGURE 26 :COURBE EMG BRAS DECONTRACTE | 22
FIGURE 27 :COURBE EMG BRAS CONTRACTE | 22
FIGURE 28 : MONTAGE SERVOMOTEUR | 23
FIGURE 29 : IDEE INITIALE DE PROTHESE | 25
FIGURE 30 : SCHEMA DE REFLEXION SUR LE MODELE A ENGRENAGE | 25
FIGURE 31 : INTERIEUR DE LA MAIN | 27
FIGURE 32 : LES PIECES DE LA MAIN | 28
FIGURE 33 :ASSEMBLAGE DE LA PLAQUE (NOIR), DES BARRES ET DES CABLES | 28
FIGURE 34 : PASSAGE DES CABLES DANS LES DOIGTS | 28
FIGURE 35 : ASSEMBLAGE DES FILS DE LIAISON | 29
FIGURE 36 : ASSEMBLAGE FINAL | 29
FIGURE 37 : SCHEMA DE L’ARTICULATION DES PHALANGES ET DES MUSCLES EXTENSEURS DU DOIGT | 30
FIGURE 38 :DOIGT DE LA PROTHESE | 30
FIGURE 39 : ENTREE DU FILS DANS LE DOIGT PAR LA PAUME | 31
FIGURE 40 : MUSCLE FLECHISSEUR PROFOND DES DOIGTS | 31
FIGURE 41 : ORGANIGRAMME PROGRAMME GLOBAL | 32
FIGURE 42 : ORGANIGRAMME VERSION 1 | 33
FIGURE 43 : ORGANIGRAMME VERSION 2 | 35

# Annexe

## Programmes Test 1 : Capteur EMG :

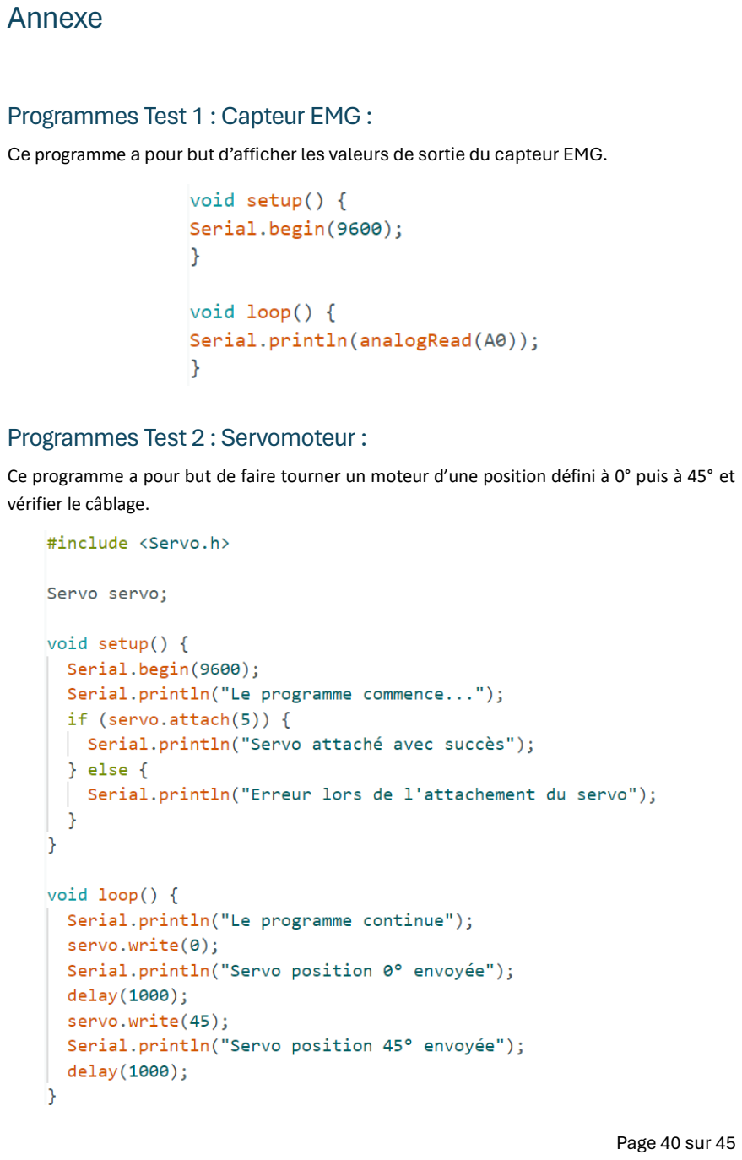
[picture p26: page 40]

### Page 40 sur 45

Ce programme a pour but d’afficher les valeurs de sortie du capteur EMG.

## Programmes Test 2 : Servomoteur :

Ce programme a pour but de faire tourner un moteur d’une position défini à 0° puis à 45° et vérifier le câblage.

### Page 41 sur 45

## Calcul théorique de la masse que peut porter chaque doigt tendu

### Page 42 sur 45

### 1) Moteur / Plaque 1

### Calcul de la force transmise par le moteur :

F =

C.g
r

### avec g la constante de gravitation

### Page 43 sur 45

### 2) Plaque 1 / Plaque 2 et 3

### Les plaques sont symétriques de part et d’autre de la pièce centrale donc :

F11 = F21

F12 = F22

### Notons F1 la force verticale total sur la plaque de gauche et respectivement F2 sur celle

de droite de même valeur (car symétrie et masse uniformément répartie).

F1 = F2 = F11y +F12y

### Il n’y a pas de mouvement selon l’axe horizontale d’où :

### Sur x : (F11 – F21) .sin(θ 1) + (F12 – F22).sin(θ 2)= 0

### De plus, F = 2F11 + 2F12 d’où :

### Sur y : 2F11.cos(θ 1)+ 2F12 .cos(θ 2)= - F = -

Cg
r

F11 =

0 sin(θ2)
−

Cg
r

cos(θ2)

sin(ϴ1).cos(ϴ2)−cos(ϴ1).sin(ϴ2)

=

Cg⋅sin(θ2)
2r⋅sin(θ1−θ2)

F12 =

sin(θ1) 0)
cos(θ2) −

Cg
r

)

sin(ϴ1).cos(ϴ2)−cos(ϴ1).sin(ϴ2)

=

− Cg⋅sin(θ1)
2r⋅sin(θ1−θ2)

### F11y = F11 . cos(θ 1)

### F12y = F12 . cos(θ 2)

### Donc F1 = F11 . cos(θ 1) + F12 . cos(θ 2) =

Cg⋅sin(θ2) cos(θ1)
2r⋅sin(θ1−θ2)

Cg⋅sin(θ1) cos(θ2)
2r⋅sin(θ1−θ2)
F1 =

F
2

sin(θ2−θ1)
sin(θ1−θ2)

= F2

### Page 44 sur 45

### 3) Plaque 2 ou 3 / doigt

### Calcul du moment en A :

MA = F1 . d1levier

d1levier = d1 . cos(θ3)

### MA = F1 . d1 . cos(θ3)

### Même principe en B :

MB = F1 . d2levier

d2levier = d2 . cos(θ4)

### MB = F1 . d2 . cos(θ4)

Faire de même pour les points C et D.

### Page 45 sur 45

### 4) Force maximale à l’extrémité du doigt

A faire pour chacun des doigts.

### P = mg

### Exemple avec le moment A :

### MA = P . dA en combinant avec les résultats précédents :

MMAX = F1 .

d1.cos (θ3)
gdA
=

F
2

sin(θ2−θ1)
sin(θ1−θ2)

d1.cos (θ3)
gdA
=

C.g
2.r

sin(θ2−θ1)
sin(θ1−θ2)

d1.cos (θ3)
gdA

Dans ces approximations, nous n’avons pas pris en compte les frottements qui ont lieu lors du mouvement des différentes pièces, il faudrait les prendre en compte pour avoir des résultats réels puisque lors de l’utilisation de notre main, nous avons constaté qu’ils étaient très importants. De plus nous n’avons pas pris en compte la force élastique car nous les avons rajoutés en fin de projet.

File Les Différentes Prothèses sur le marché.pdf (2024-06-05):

Modèles | Entreprise / Association | Apparence | Prix (en euros) | Controle

Myo; Nous; EMG
Prothèse e-Nable; e-Nable; Mécanique; Hero Arms; Open Bionics; EMG

TrueLimb® Prosthetic Arm | Unlimited Tomorrow | | 7 500 | EMG (capteurs TrueLimb®)
TASKA HandGen2 | TASKA Prostetics | | 18 500 – 92 000 | EMG et boutons sur main

Phamtom Lim Bionic | OpenBionics | 55 000 | EMG


DynamicArm BeBionic | Ottobock | 65 000 | EMG
LUKE arm | Mobius bionics | 92 000 | EMG et commandes externes

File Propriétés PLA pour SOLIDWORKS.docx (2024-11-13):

Propriété du PLA sur Solidworks :

A partir de recherche faites sur internet nous avons pu créer un nouveau matériau qui modéliserait le PLA utilisé par les imprimantes de l’école.


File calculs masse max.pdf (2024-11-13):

Calcul de la masse que peut porter chaque doigt tendu


1) Moteur / Plaque 1


Calcul de la force transmise par le moteur :

F =

C
r

2) Plaque 1 / Plaque 2 et 3


Les plaques sont symétriques de part et d’autre de la pièce centrale donc :

F11 = F21

F12 = F22
Notons F1 la force verticale total sur la plaque de gauche et respectivement F2 sur celle de droite de même valeur (car symétrie et masse uniformément répartie).

F1 = F2 = F11y +F12y
F = 2F11 + 2F12
Sur x : 2F11.sin(θ 1)+ 2F12 .sin(θ 2)= 0

Sur y : 2F11.cos(θ 1)+ 2F12 .cos(θ 2)= - F = -

C
r

F11 =

0 sin(θ2)
−

C
r

cos(θ2)

sin(ϴ1).cos(ϴ2)−cos(ϴ1).sin(ϴ2)

=

C⋅sin(θ2)
2r⋅sin(θ1−θ2)

F12 =

sin(θ1) 0)
cos(θ2) −

C
r

)

sin(ϴ1).cos(ϴ2)−cos(ϴ1).sin(ϴ2)

=

− C⋅sin(θ1)
2r⋅sin(θ1−θ2)
F11y = F11 . cos(θ 1)
F12y = F12 . cos(θ 2)

Donc F1 = F11 . cos(θ 1) + F12 . cos(θ 2) =

C⋅sin(θ2) cos(θ1)
2r⋅sin(θ1−θ2)

C⋅sin(θ1) cos(θ2)
2r⋅sin(θ1−θ2)
F1 =

F
2

sin(θ2−θ1)
sin(θ1−θ2)

3) Plaque 2 ou 3 / doigt


Calcul du moment en A :

MA = F1 . d1levier

d1levier = d1 . cos(θ3)
MA = F1 . d1 . cos(θ3)
Même principe en B :

MB = F1 . d2levier

d2levier = d2 . cos(θ4)
MB = F1 . d2 . cos(θ4)

Faire de même pour les points C et D.

4) Force maximale à l’extrémité du doigt A faire pour chacun des doigts.


P = mg
Exemple avec le moment A :
MA = P . dA en combinant avec les résultats précédents :

m = F1 .

d1.cos (θ3)
gdA

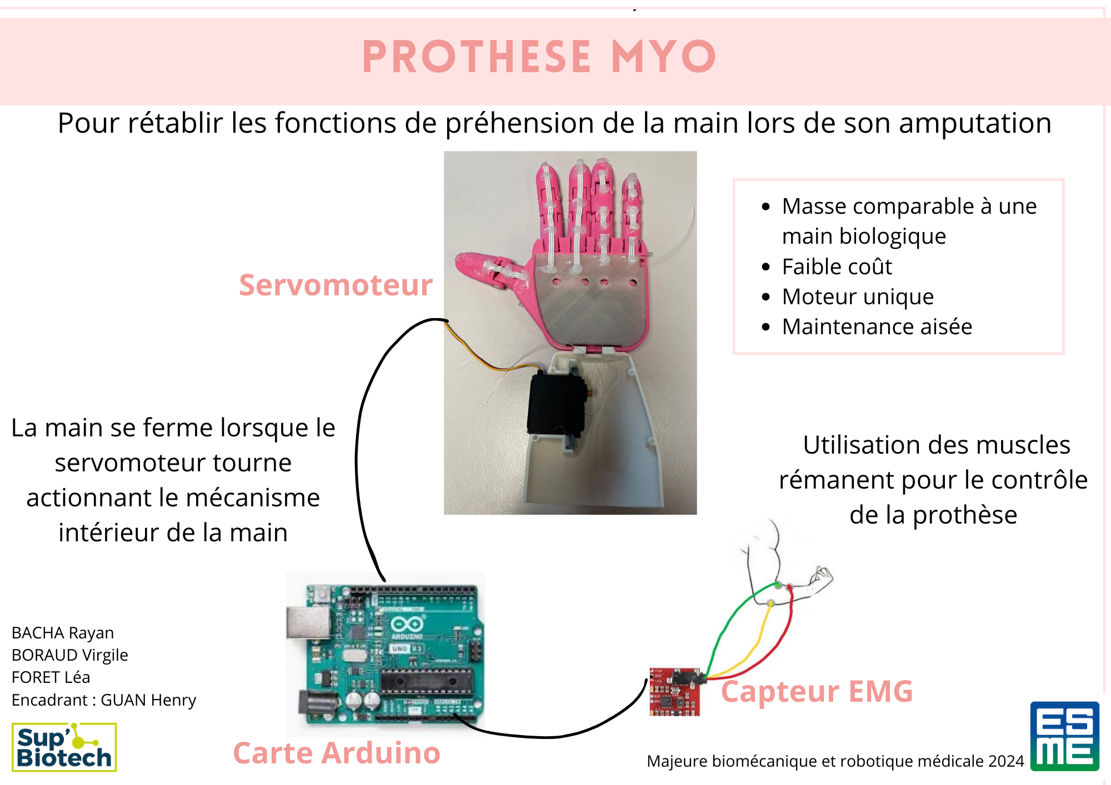
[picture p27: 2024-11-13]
Affiche _2B09.png

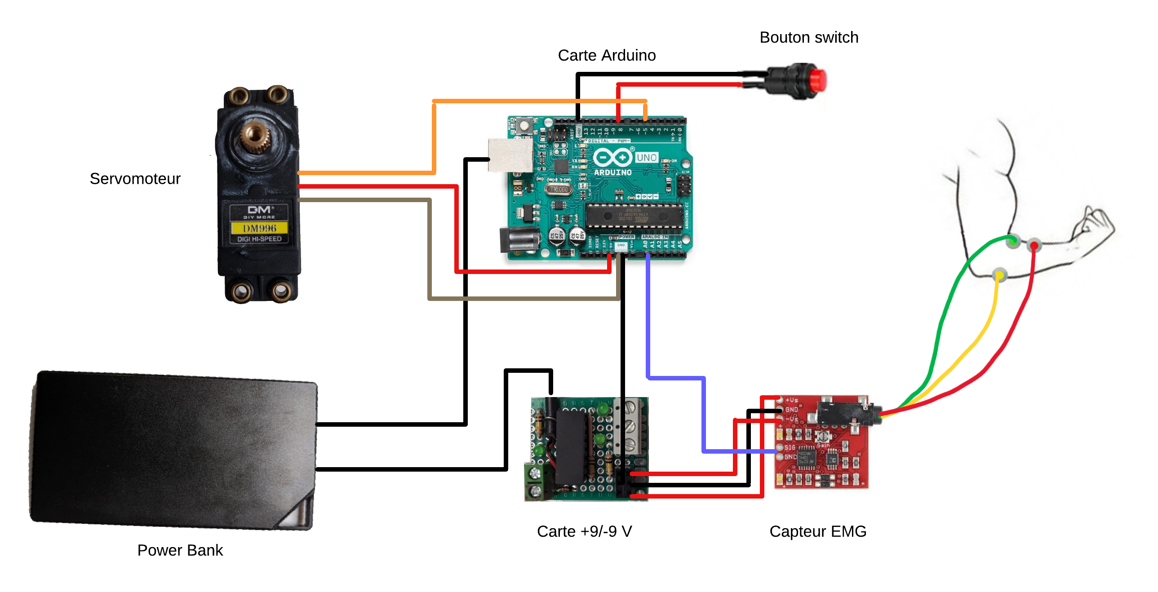
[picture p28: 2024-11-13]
schéma_électrique.png

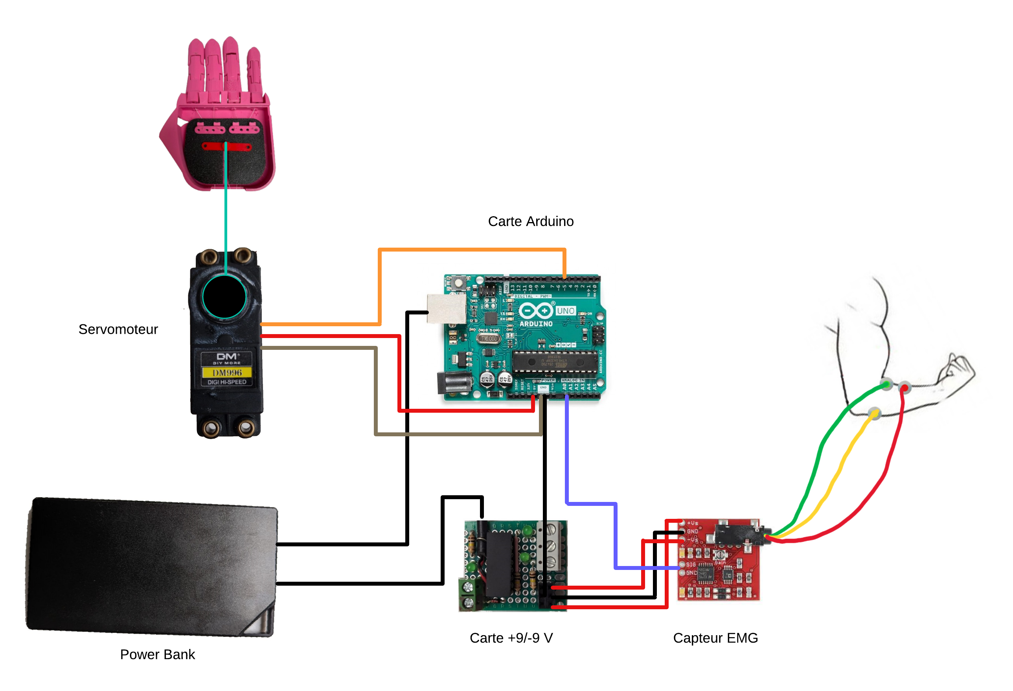
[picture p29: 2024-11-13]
Schéma synoptique projet.png

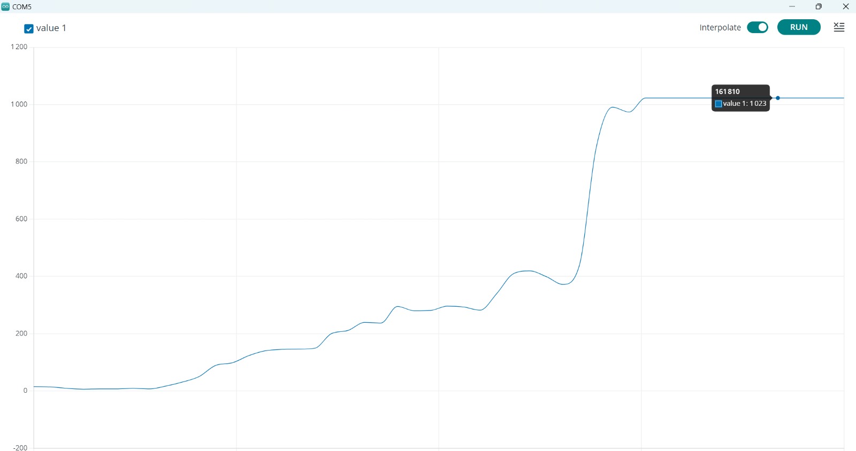
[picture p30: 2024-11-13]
Programmes/affichage_capteur_EMG/contracté.jpg

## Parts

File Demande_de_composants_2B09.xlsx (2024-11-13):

Groupe : | 2B09 |  |  |  | NON URGENT |  |  |  | Informations, remarques, détail des quantités etc…
Projet : | Avant-Bras Myoélectrique
Assistant de projet : | GUAN Henry |  |  |  |  |  | Document => |  | Lien (s) de l'équivalent | Pour éviter les doutes donc les erreurs Notez ici la Quantité que je vous auriez saisie dans le pannier du fournisseur. | OK, remarques ou autre | Validation du nouveau composant par le groupe et le référent | Descriptif
Mail élève pour suivi : | lea.foret@esme.fr |  | Lien de BOOM, Panier etc. |  | TOTAL : | 96.41 | Commande =>
Lien "cliquable" | Nom du Composant | Fournisseur : | Code fournisseur | QT utile | PRIX TTC | Prix Total | Cellules Vides ou OK = Réferent OK | INFOS Pointage
https://www.conrad.fr/fr/p/reely-servomoteur-standard-s3003-mg-analogique-materiau-entrainement-metal-systeme-de-connecteur-jr-2234101.html | Servo Moteur (S3003) | CONRAD | RE-6702303 | 1 | 20.99 | 20.99 | OK |  |  |  |  |  | #REF!
https://www.amazon.fr/Wal-Capteur-%C3%A9lectromyographique-Frontal-Connexion/dp/B082NCZ43Q?th=1 | Capteur EMG (Muscle Sensor v3) | l@TELIER | B082NCZ43Q | 1 | 30.83 | 30.83 | OK |  |  |  |  |  | B082NCZ43Q / Capteur EMG (Muscle Sensor v3)
https://www.gotronic.fr/art-arduino-uno-r4-minima-abx00080-37366.htm | Microprocesseur (Arduino uno) | l@TELIER |  | 1 | 21.6 | 21.6 | OK |  |  |  |  |  | / Microprocesseur (Arduino uno)
https://www.conrad.fr/fr/p/powerbank-batterie-supplementaire-varta-power-bank-energy-10000-10000-mah-lipo-usb-c-blanc-noir-2338727.html | batterie powerbank | CONRAD | 57976101111 | 1 | 22.99 | 22.99 | OK |  |  |  |  |  | 57976101111 / batterie powerbank
 | carte +9/-9V | l@TELIER |  | 1 |  |  | OK |  |  |  |  |  | RE-6702303 / carte +9/-9V
 |  |  |  |  |  |  |  |  |  |  |  |  | /
 |  |  |  |  |  |  |  |  |  |  |  |  | /
 |  |  |  |  |  |  |  |  |  |  |  |  | /
 |  |  |  |  |  |  |  |  |  |  |  |  | /
 |  |  |  |  |  |  |  |  |  |  |  |  | /
 |  |  |  |  |  |  |  |  |  |  |  |  | /
 |  |  |  |  |  |  |  |  |  |  |  |  | /
 |  |  |  |  |  |  |  |  |  |  |  |  | /
 |  |  |  |  |  |  |  |  |  |  |  |  | /
 |  |  |  |  |  |  |  |  |  |  |  |  | /
 |  |  |  |  |  |  |  |  |  |  |  |  | /
 |  |  |  |  |  |  |  |  |  |  |  |  | /
 |  |  |  |  |  |  |  |  |  |  |  |  | /
 |  |  |  |  |  |  |  |  |  |  |  |  | /
 |  |  |  |  |  |  |  |  |  |  |  |  | /
 |  |  |  |  |  |  |  |  |  |  |  |  | /
 |  |  |  |  |  |  |  |  |  |  |  |  | /
 |  |  |  |  |  |  |  |  |  |  |  |  | /
 |  |  |  |  |  |  |  |  |  |  |  |  | /
 |  |  |  |  |  |  |  |  |  |  |  |  | /
 |  |  |  |  |  |  |  |  |  |  |  |  | /
 |  |  |  |  |  |  |  |  |  |  |  |  | /
 |  |  |  |  |  |  |  |  |  |  |  |  | /
 |  |  |  |  |  |  |  |  |  |  |  |  | /
 |  |  |  |  |  |  |  |  |  |  |  |  | /
 |  |  |  |  |  |  |  |  |  |  |  |  | /
 |  |  |  |  |  |  |  |  |  |  |  |  | /
 |  |  |  |  |  |  |  |  |  |  |  |  | /
 |  |  |  |  |  |  |  |  |  |  |  |  | /
 |  |  |  |  |  |  |  |  |  |  |  |  | /
 |  |  |  |  |  |  |  |  |  |  |  |  | /
 |  |  |  |  |  |  |  |  |  |  |  |  | /
 |  |  |  |  |  |  |  |  |  |  |  |  | /
 |  |  |  |  |  |  |  |  |  |  |  |  | /
 |  |  |  |  |  |  |  |  |  |  |  |  | /
 |  |  |  |  |  |  |  |  |  |  |  |  | /
 |  |  |  |  |  |  |  |  |  |  |  |  | /
 |  |  |  |  |  |  |  |  |  |  |  |  | /
 |  |  |  |  |  |  |  |  |  |  |  |  | /
 |  |  |  |  |  |  |  |  |  |  |  |  | /

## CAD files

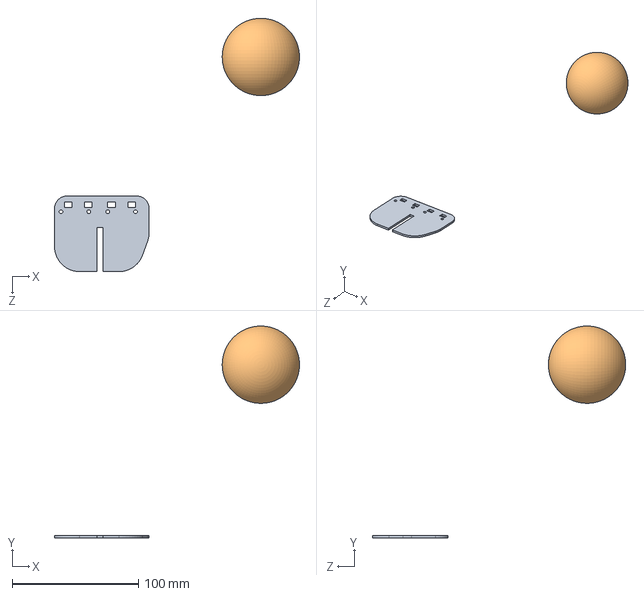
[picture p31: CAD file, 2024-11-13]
CAO/Pièce milieu paume.SLDASM
194.1 x 167.9 x 200.7 mm

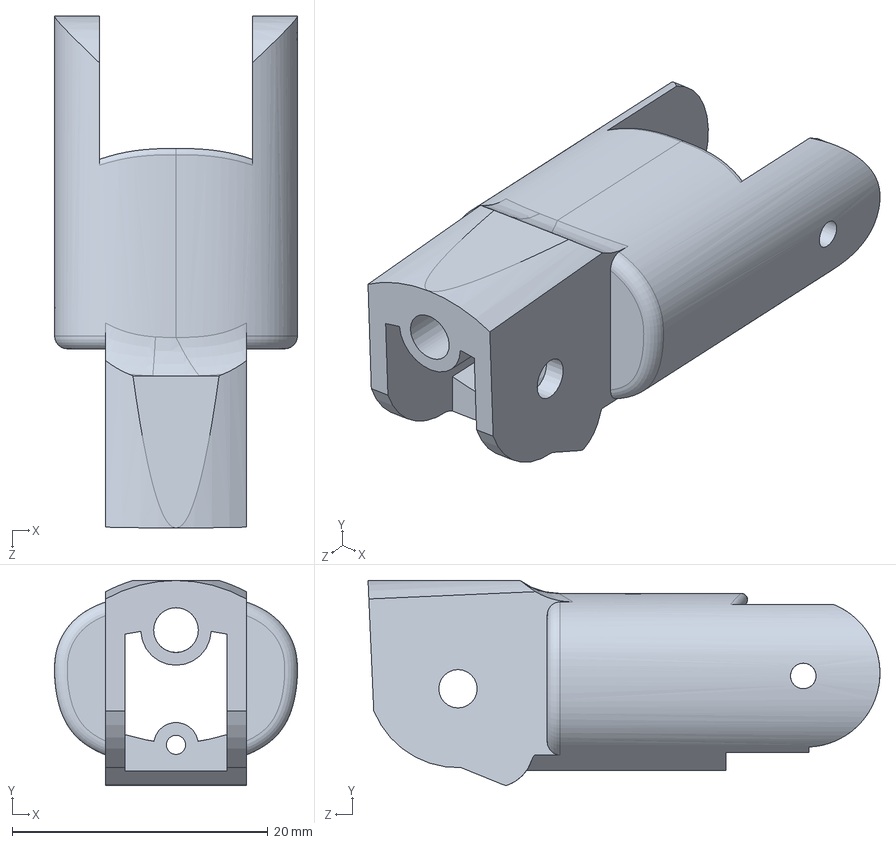
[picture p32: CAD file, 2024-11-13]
CAO/Middle Finger Bottom Proximal.SLDPRT
19.0 x 16.0 x 40.0 mm

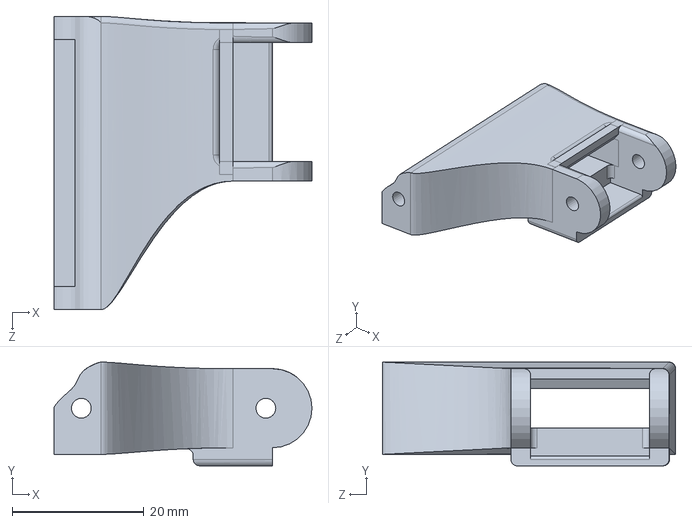
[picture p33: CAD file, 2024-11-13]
CAO/Thumb Lower.SLDPRT
39.1 x 15.8 x 44.5 mm

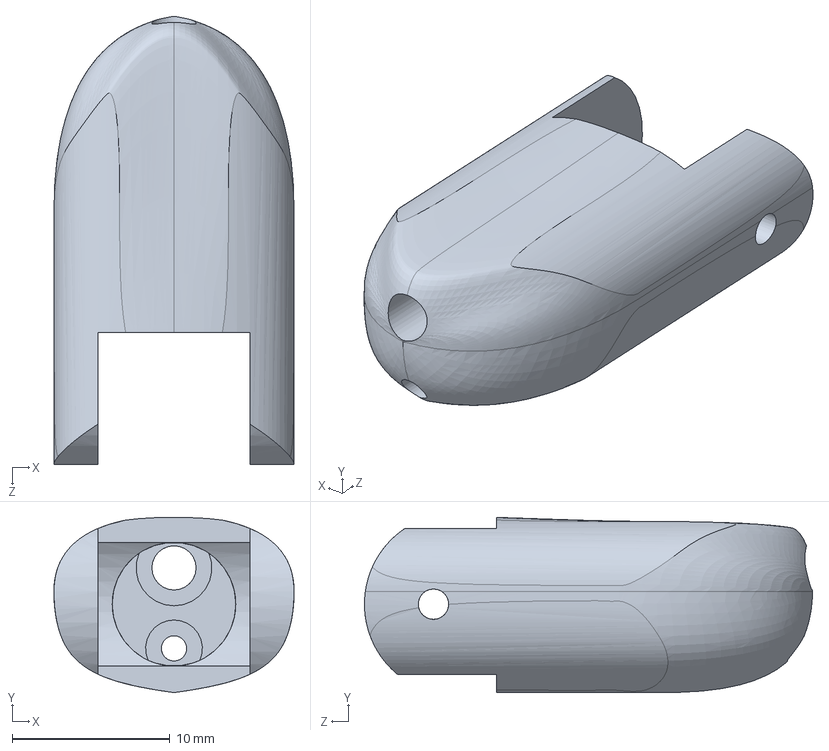
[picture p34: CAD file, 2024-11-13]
CAO/Pinky Finger Distal.SLDPRT
15.2 x 11.1 x 28.4 mm

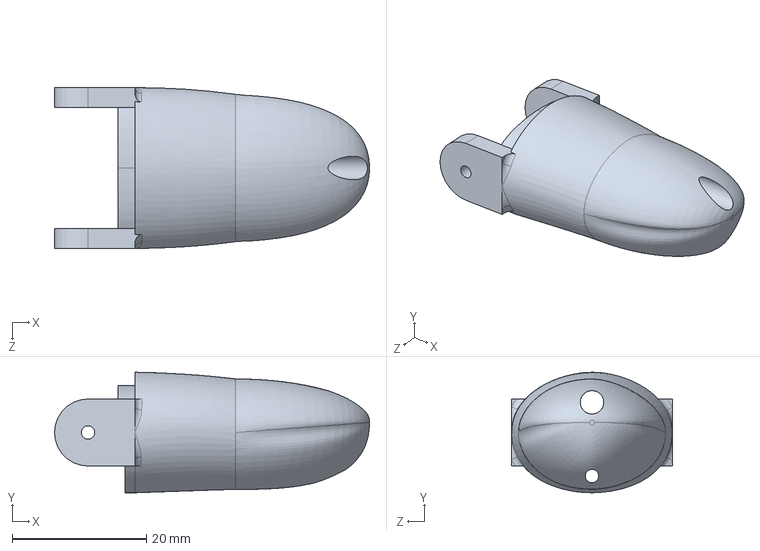
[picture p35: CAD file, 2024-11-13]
CAO/Thumb tip 2.SLDPRT
47.0 x 18.0 x 24.0 mm

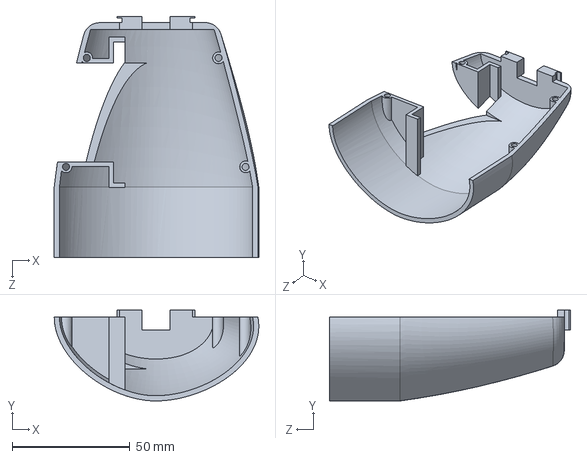
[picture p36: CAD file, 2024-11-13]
CAO/Pièce haut avant bras.SLDPRT
87.0 x 38.7 x 102.4 mm

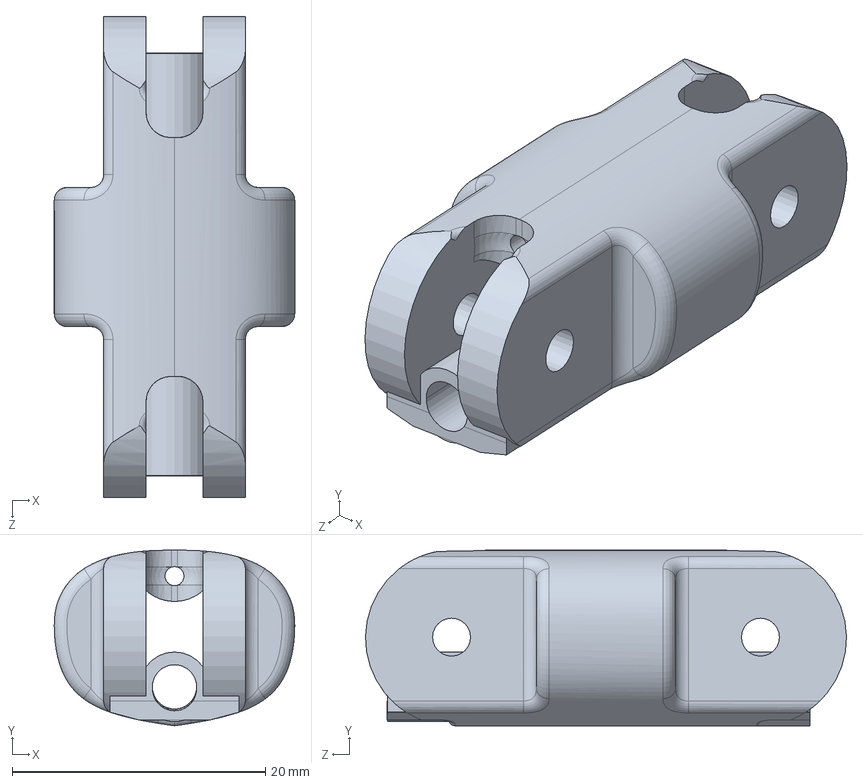
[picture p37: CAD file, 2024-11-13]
CAO/Ring Finger Middle.SLDPRT
19.0 x 13.9 x 38.0 mm

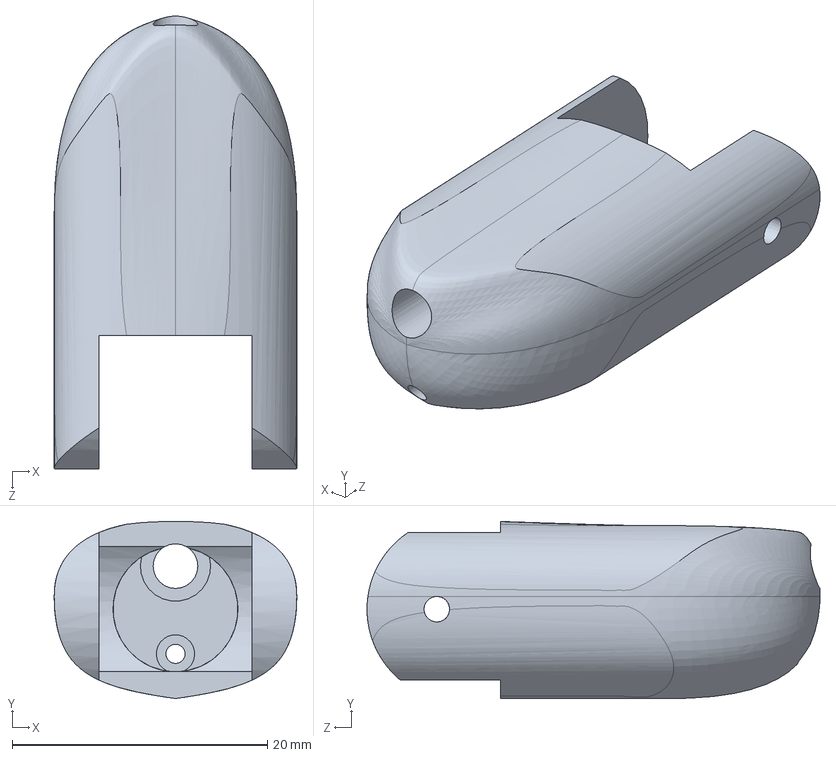
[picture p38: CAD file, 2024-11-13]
CAO/Ring Finger Distal.SLDPRT
19.0 x 13.9 x 35.5 mm

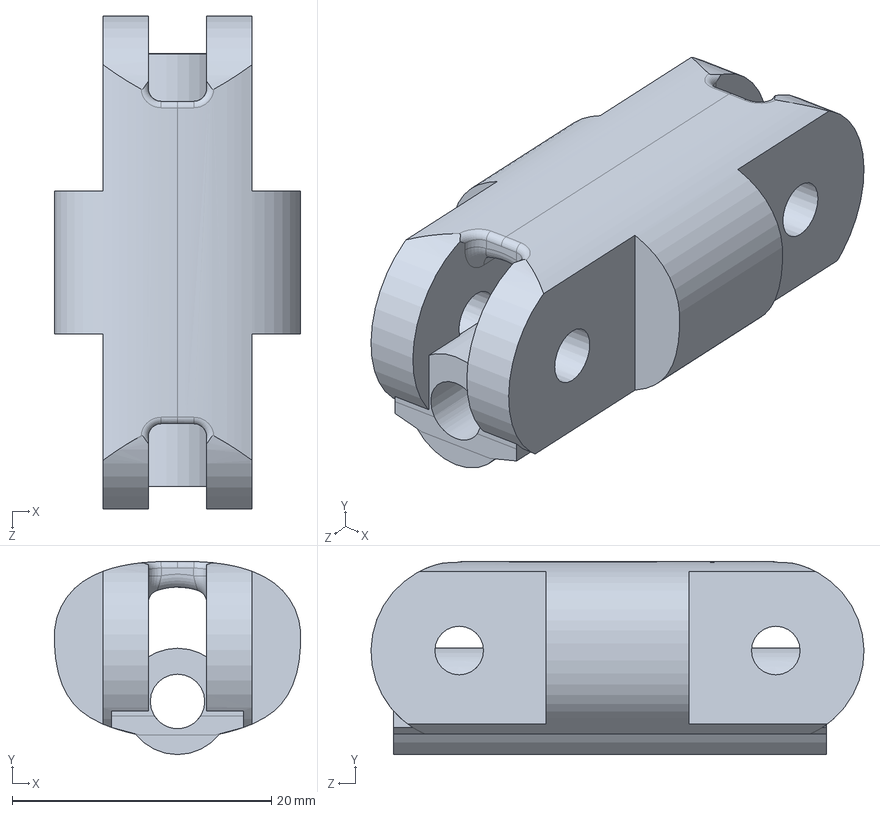
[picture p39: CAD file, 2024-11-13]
CAO/Pinky Finger Middle.SLDPRT
19.0 x 14.9 x 38.0 mm

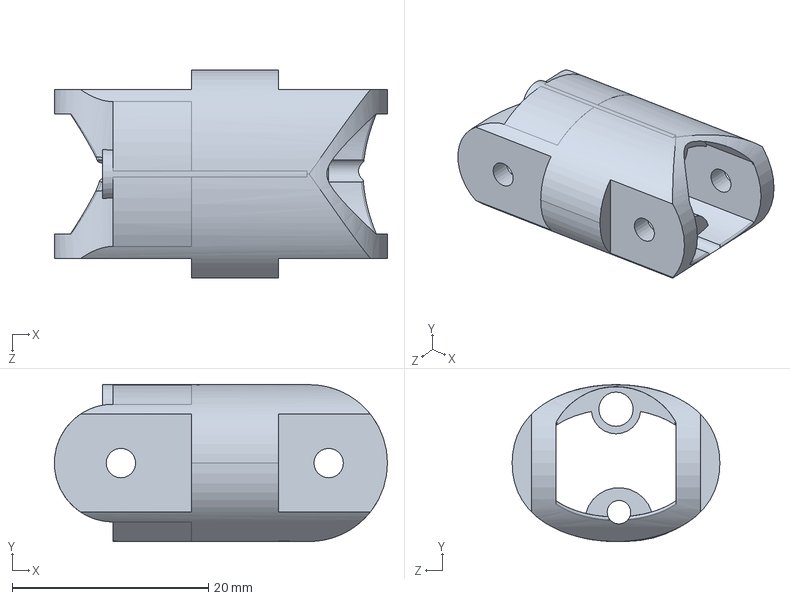
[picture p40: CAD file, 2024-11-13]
CAO/Thumb Middle.SLDPRT
34.0 x 16.0 x 21.2 mm

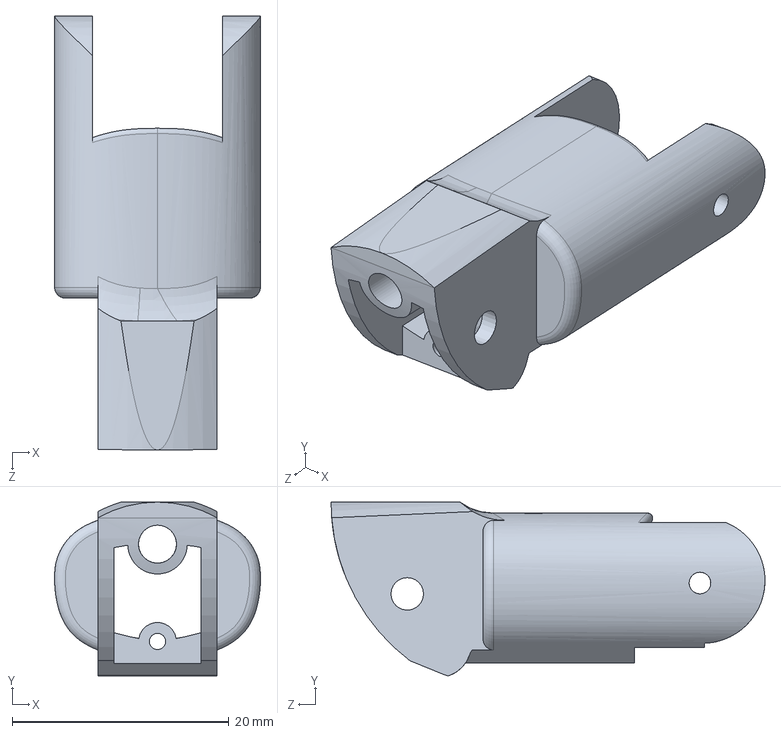
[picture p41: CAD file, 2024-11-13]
CAO/Index Finger Bottom Proximal.SLDPRT
19.0 x 16.0 x 40.0 mm

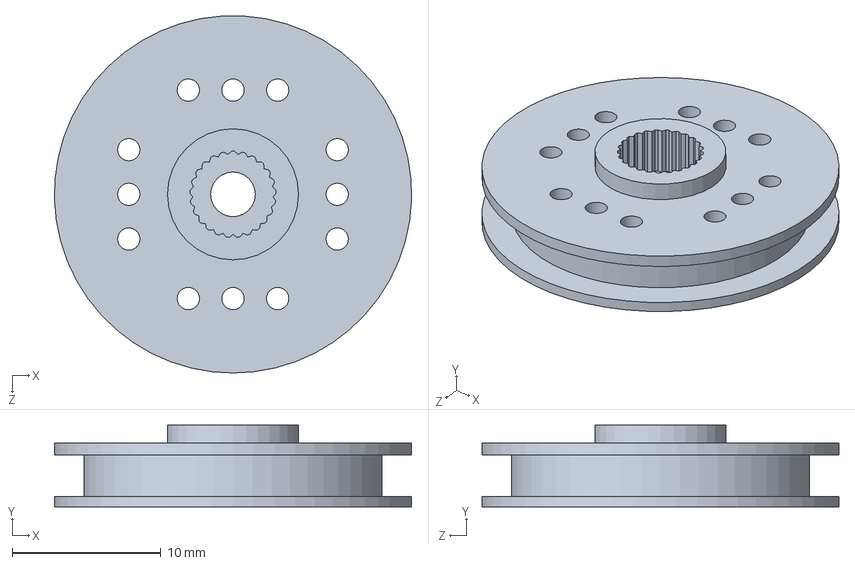
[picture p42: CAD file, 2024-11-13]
CAO/Pièce poulie moteur.SLDPRT
24.0 x 5.50 x 24.0 mm

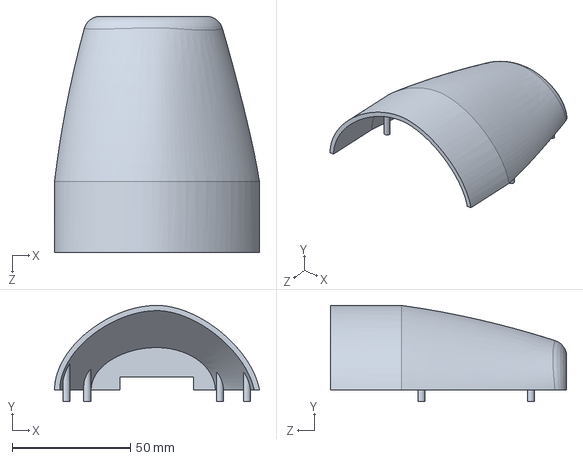
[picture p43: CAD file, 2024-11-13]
CAO/Pièce bas avant bras.SLDPRT
86.6 x 40.7 x 99.8 mm

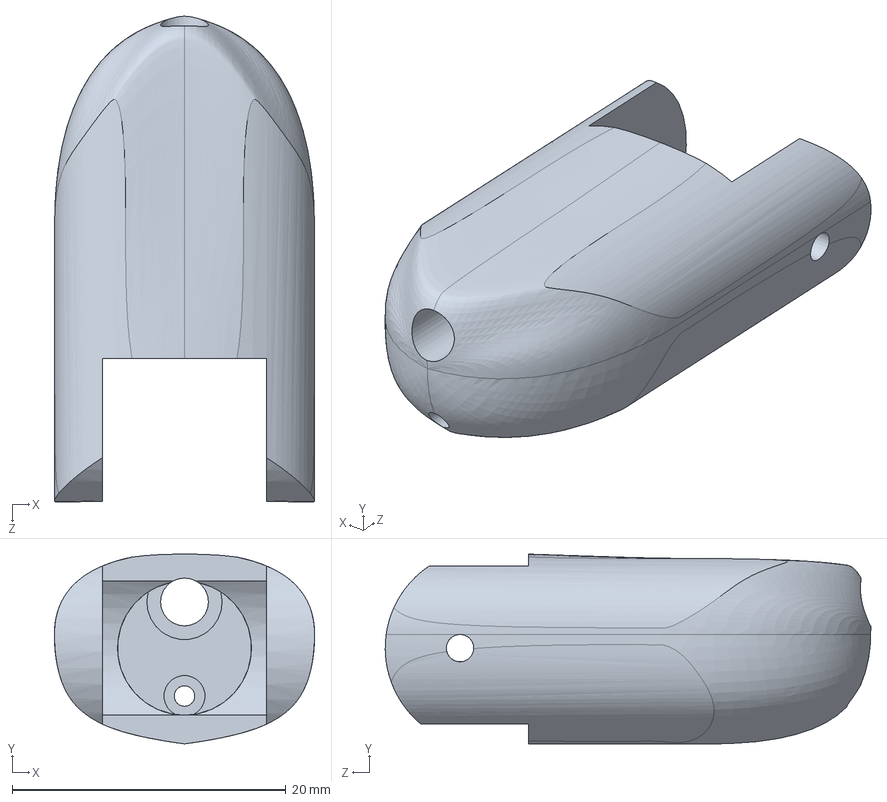
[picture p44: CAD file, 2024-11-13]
CAO/Index Finger Distal.SLDPRT
19.0 x 13.9 x 35.5 mm

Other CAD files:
CAO/Ring Finger Bottom Proximal.SLDPRT
CAO/Middle Finger Middle.SLDPRT
CAO/Middle Finger Distal.SLDPRT
CAO/Index Finger Middle.SLDPRT
CAO/Pinky Finger Bottom Proximal.SLDPRT

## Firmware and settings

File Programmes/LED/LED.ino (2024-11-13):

void setup()    // début de la fonction setup()
{
    pinMode(13, OUTPUT);  // Initialise la broche 13 comme sortie
    Serial.begin(9600);   // Ouvre le port série à 9600 bauds
    Serial.println("Le programme démarre...");
}               // fin de la fonction setup()

//***** FONCTION LOOP = Boucle sans fin = cœur du programme *****
// la fonction loop() s'exécute sans fin en boucle aussi longtemps que l'Arduino est sous tension

void loop()     // début de la fonction loop()
{
    digitalWrite(13, HIGH);  // Met la broche 13 au niveau haut = allume la LED
    delay(500);              // Pause de 500 ms
    digitalWrite(13, LOW);   // Met la broche 13 au niveau bas = éteint la LED
    delay(500);              // Pause 500 ms
}               // fin de la fonction loop()

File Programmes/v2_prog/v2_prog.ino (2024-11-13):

#include <Servo.h> 
Servo servo;

// Déclaration des constantes
const int pinEMG = A0;      // Pin sur lequel est connecté le capteur EMG
const int seuil = 700;      // Seuil pour déclencher un changement d'état
int etat =0;                // Etat initial, 0 = ouvert, 1 = fermé


void setup() {
  Serial.begin(9600);     // Initialise la communication avec l'arduino
  servo.attach(5);        // servo connecté pin 5
  servo.write(0);         // position de départ
}

void loop() {
  int valeurEMG = analogRead(pinEMG);     // Lecture de la valeur du capteur EMG
  Serial.println(valeurEMG);              //Permet d'afficher les valeurs si besoin de recalibrer

  while(valeurEMG > seuil){           // Tant que le seuil est dépassé
    servo.write(180);                 // met le moteur en position fermé
    etat=1;                           // changement d'état
    valeurEMG = analogRead(pinEMG);   // nouvelle mesure de l'emg
  }
  etat=0;           //changement d'état
  servo.write(0);   // position ouvert
}

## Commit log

2024-05-03 Code of the arduino
2024-11-13 Add CAO
    [Index Finger Bottom Proximal.SLDPRT, Index Finger Distal.SLDPRT, Index Finger Middle.SLDPRT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]
2024-11-13 Add others
    [Demande_de_composants_2B09.xlsx]
